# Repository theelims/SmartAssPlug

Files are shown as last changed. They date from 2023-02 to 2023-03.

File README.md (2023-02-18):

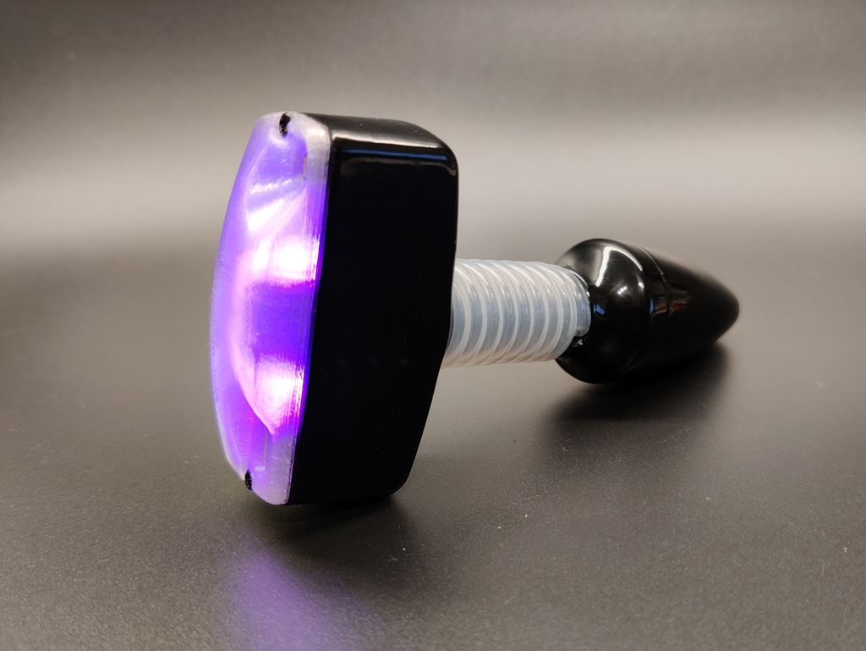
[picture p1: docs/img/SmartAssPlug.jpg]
SmartAss Plug


# SmartAss Plug - A Smart Butt Plug

Everything becomes "smart" these days. And there is no exception for butt plugs. While many butt plugs claim "smartness", just connecting it to the internet typically only means a remote control with more range. However **SmartAss Plug** has some more tricks up its sleeves. It's main purpose is not to vibrate a butt, but to sense and gauge sexual arousal. Having a reliable way to measure sexual arousal and orgasms opens up many possibility for the kinky minded person. Pneumatic anal probes have long time being the preferred choice in the clinical sector. However, in the kinky maker space the inflatable butt plug has gained more traction. Not least because of open source projects like the [nogasm](https://github.com/nogasm/nogasm) and the [protogasm](https://github.com/night-howler/protogasm). However, the inflatable butt plug suffers from a really bad signal to noise ratio. **SmartAss Plug** tries to build on these groundwork adding a more reliable sensor element, a more robust clench detection algorithm utilizing a kalman filter and calculus. All in a self-contained unit doing away any trip wires. In order to control a pleasure inducing device it connects to [XToys](https://xtoys.app/) or [buttplug.io](https://buttplug.io/) / [infitface](https://github.com/intiface/intiface-central).

Naturally it vibrates, too (kind of a the minimum requirement, obviously) and comes with more fun like a 9-DoF IMU and RGB Leds. Because, why not?

And last but not least, you are finally able to serve a website straight from your ass. How far has humanity come?

## Features

- Measures the involuntarily clenches of the pelvic floor to derive the arousal level of the wearer.
- Arousal classifier with the states "neutral", "aroused", "edging" or "orgasm".
- Vibration motor (plug sizes S & M only) for feedback, cheating in chess or stimulation.
- 9-DoF IMU to determine the absolute position of the plug for position training. (Not implemented, yet)
- Connects to your Wi-Fi or creates its own access point.
- Internal webserver to serve you the user interface straight from your butt.
- The inevitable RGB-led to make your butt shine colorful.
- Open WebSocket based API to integrate with your projects. (XToys and Buttplug.io support are pending)

## F.A.Q.

### What is the benefit of the coiled tube over an inflatable butt plug?

Using an inflatable butt plug is the traditional approach for edging and orgasm detection as introduced by the original nogasm. However, using this comes with some notable downsides. For some the size of these plugs can be daunting. Also the inflated portion - which is the actual sensor - sits behind the anal sphincter most of the time. As the signal we are looking for is the involuntarily clenching of the pelvic floor, the signal to noise ratio of an inflatable butt plug is not that great. It does pick up a lot of noise like breathing or even the heart beat. These signals can falsely trigger the algorithm leading to unsatisfying results. The coiled silicone tube sits exactly where the clenches happen resulting in a much cleaner signal to start with.

### Where can I buy this?

So far you can't buy it. You need to build it yourself sourcing all the required materials on your own. Consult the [sourcing guide](https://theelims.github.io/SmartAssPlug/sourcing/) for more information.

### Does it integrate with XToys or Buttplug.io?

SmartAss Plug offers a WebSocket API which makes it easy to integrate. XToys and Buttplug.io support is planned, but not implemented, yet.

### Is it available in different sizes?

Yes, the plug is available in 3 different sizes to accommodate a wide range of tastes.

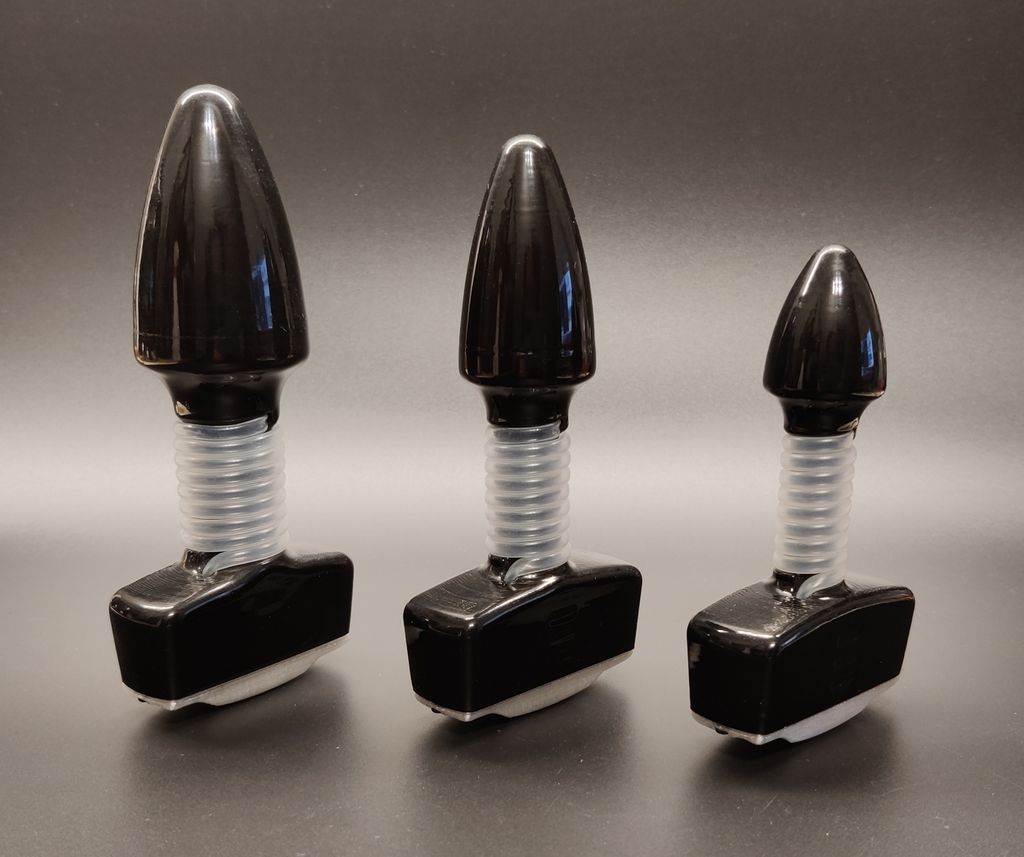
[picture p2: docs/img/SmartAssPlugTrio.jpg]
SmartAss Plug


|  Size  | Vibration | Diameter |
| :----: | :---: | :---: |
| **XS** | No |  25 mm |
| **S**  | Yes |  30 mm |
| **M**  | Yes |  38 mm |

## Contributors and Sources of Inspiration

- **Rudolf**, who came up with the [coiled silicone tube](https://www.thingiverse.com/thing:3543727) as sensor element and even has written a [scientific paper](https://www.degruyter.com/document/doi/10.1515/pjbr-2020-0014/pdf) on that topic.
- **Rhobot** with the original [nogasm project](https://github.com/nogasm/nogasm)
- **Onwrikbaar** with his bullfrog, who refined the simple [nogasm algorithm](https://github.com/Onwrikbaar/Bullfrog) with a peak summation and decay function.
- **night-howler** who contributed a breadboard friendly version of the nogasm called [protogasm](https://github.com/night-howler/protogasm).
- **Maus-Tec** who manufactures and sells the [Edge-O-Matic](https://github.com/MausTec/edge-o-matic-3000)
- **Skier23** who curates a [repository](https://github.com/Edging-Machines/Edging-Machines) and [discord](https://discord.gg/EvYbZBf) with all information regarding the topic.
- **Alex-R&D**

## License

Copyright &copy; 2023 by <a href="https://github.com/theelims"  target="_blank" rel="noopener">elims</a>

All work - software and hardware - is licensed under the

Creative Commons Attribution-ShareAlike 4.0 International Public License\*\*

For a full text of the license visit [CC-BY-SA 4.0](https://creativecommons.org/licenses/by-sa/4.0/).

# For further information visit the [project site](https://theelims.github.io/SmartAssPlug/).

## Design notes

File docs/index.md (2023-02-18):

---
hide:
  - navigation
  - toc
---

!!! warning "This project is in a very early stage"

    This project is in its infancy. The PCB may still contain undiscovered bugs. And a firmware is not yet available. Do not attempt to recreate this unless you really know what you are doing and want to contribute to this project.

<figure markdown>
  SmartAss Plug
</figure>

# SmartAss Plug - A Smart Butt Plug

Everything becomes "smart" these days. And there is no exception for butt plugs. While many butt plugs claim "smartness", just connecting it to the internet typically only means a remote control with more range. However **SmartAss Plug** has some more tricks up its sleeves. It's main purpose is not to vibrate a butt, but to sense and gauge sexual arousal. Having a reliable way to measure sexual arousal and orgasms opens up many possibility for the kinky minded person. Pneumatic anal probes have long time being the preferred choice in the clinical sector. However, in the kinky maker space the inflatable butt plug has gained more traction. Not least because of open source projects like the [nogasm](https://github.com/nogasm/nogasm) and the [protogasm](https://github.com/night-howler/protogasm). However, the inflatable butt plug suffers from a really bad signal to noise ratio. **SmartAss Plug** tries to build on these groundwork adding a more reliable sensor element, a more robust clench detection algorithm utilizing a kalman filter and calculus. All in a self-contained unit doing away with trip wires. In order to control a pleasure inducing device it connects to [XToys](https://xtoys.app/) or [buttplug.io](https://buttplug.io/) / [infitface](https://github.com/intiface/intiface-central).

Naturally it vibrates, too (kind of a minimum requirement, obviously) and comes with more fun like a 9-DoF IMU and RGB Leds. Because, why not?

And last but not least, you are finally able to serve a website straight from your ass. How far has humanity come?

## Features

- Measures the involuntarily clenches of the pelvic floor to derive the arousal level of the wearer.
- Arousal classifier with the states "neutral", "aroused", "edging" or "orgasm".
- Vibration motor (plug sizes S & M only) for feedback, cheating in chess or stimulation.
- 9-DoF IMU to determine the absolute position of the plug for position training. (Not implemented, yet)
- Connects to your Wi-Fi or creates its own access point.
- Internal webserver to serve you the user interface straight from your butt.
- The inevitable RGB-led to make your butt shine colorful.
- Open WebSocket based API to integrate with your projects. (XToys and Buttplug.io support are pending)

## F.A.Q.

### What is the benefit of the coiled tube over an inflatable butt plug?

Using an inflatable butt plug is the traditional approach for edging and orgasm detection as introduced by the original nogasm. However, using this comes with some notable downsides. For some the size of these plugs can be daunting. Also the inflated portion - which is the actual sensor - sits behind the anal sphincter most of the time. As the signal we are looking for is the involuntarily clenching of the pelvic floor, the signal to noise ratio of an inflatable butt plug is not that great. It does pick up a lot of noise like breathing or even the heart beat. These signals can falsely trigger the algorithm leading to unsatisfying results. The coiled silicone tube sits exactly where the clenches happen resulting in a much cleaner signal to start with.

### Where can I buy this?

So far you can't buy it. You need to build it yourself sourcing all the required materials on your own. Consult the [sourcing guide](sourcing.md) for more information.

### Does it integrate with XToys or Buttplug.io?

SmartAss Plug offers a WebSocket API which makes it easy to integrate. XToys and Buttplug.io support is planned, but not implemented, yet.

### Is it available in different sizes?

Yes, the plug is available in 3 different sizes to accommodate a wide range of tastes.

SmartAss Plug

|  Size  | Vibration | Diameter |
| :----: | :---: | :---: |
| **XS** | :material-close: |  25 mm |
| **S**  | :material-check: |  30 mm |
| **M**  | :material-check: |  38 mm |

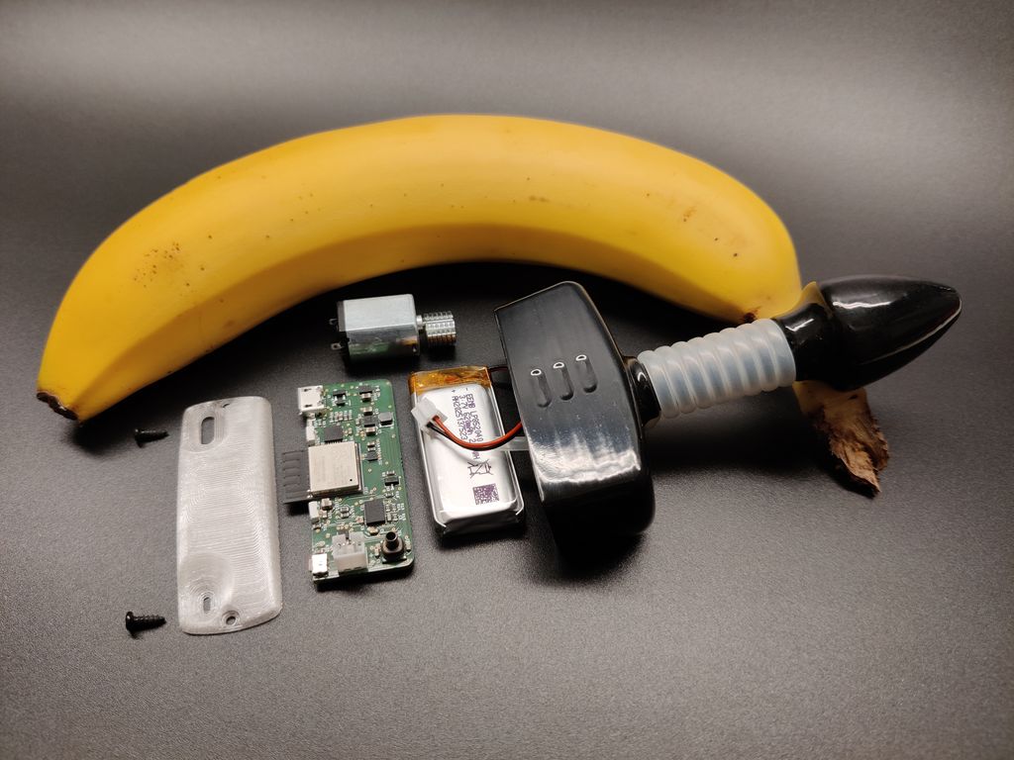
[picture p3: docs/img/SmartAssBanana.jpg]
SmartAss Plug


## Contributors and Sources of Inspiration

- **Rudolf**, who came up with the [coiled silicone tube](https://www.thingiverse.com/thing:3543727) as sensor element and even has written a [scientific paper](https://www.degruyter.com/document/doi/10.1515/pjbr-2020-0014/pdf) on that topic.
- **Rhobot** with the original [nogasm project](https://github.com/nogasm/nogasm)
- **Onwrikbaar** with his bullfrog, who refined the simple [nogasm algorithm](https://github.com/Onwrikbaar/Bullfrog) with a peak summation and decay function.
- **night-howler** who contributed a breadboard friendly version of the nogasm called [protogasm](https://github.com/night-howler/protogasm).
- **Maus-Tec** who manufactures and sells the [Edge-O-Matic](https://github.com/MausTec/edge-o-matic-3000)
- **Skier23** who curates a [repository](https://github.com/Edging-Machines/Edging-Machines) and [discord](https://discord.gg/EvYbZBf) with all information regarding the topic.
- **Alex-R&D**

## License

Copyright &copy; 2023 by <a href="https://github.com/theelims"  target="_blank" rel="noopener">elims</a>

All work - software and hardware - is licensed under the

**:fontawesome-brands-creative-commons: :fontawesome-brands-creative-commons-by: :fontawesome-brands-creative-commons-sa: Creative Commons Attribution-ShareAlike 4.0 International Public License**

For a full text of the license visit [CC-BY-SA 4.0](https://creativecommons.org/licenses/by-sa/4.0/).

!!! Question "Can I sell this on my webshop?"

    Yes, of course! You may start producing the PCB and the plug and sell it on your shop. The license was deliberately chosen to allow a commercial use by whoever is willing to go through the woes of starting their own business. However, the tech-kinky scene is rather limited in size and thus you must give back any improvements such that the kinky maker scene can take advantages of it. Please drop me a note if you sell it, so that I can include it into the sourcing guide.

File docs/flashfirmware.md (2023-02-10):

# Flash the Firmware

!!! info "Firmware not yet close to release"

    The firmware is still under heavy development. So far all parts of the PCB have confirmed to work as expected.

Join the [Kinky Makers Discord](https://discord.gg/hephqY2m8A) and follow the _#elims-smartass-plug-edging-device_ channel to receive regular updates on the development.

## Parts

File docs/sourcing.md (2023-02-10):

# Source all Parts

As you can't buy the plug off the shelf making it is up to you. This might be daunting at first, but if you already own a 3D printer you figured out the hard part already. But even if you don't own a printer yourself there are numerous service providers out happily accepting your money. Same goes for the electronics. You can practice SMD assembly and order the board from your preferred PCB house. Or you can throw money at the problem and get ready made and assembled boards from several sources in China.

## Tools needed

- 3D printer
- Soldering Iron + Solder (SmartAss Plug S & M only)
- Sandpaper, various grids starting from 120 and finer
- Scotch-Brite red and black
- Scissors
- Screwdriver Philipps #1
- Cleaned pickles jar, big enough for the intended plug size
- Acetone
- Paper Towel
- Acetone-proof brush
- IPA and lint-free cloth
- fine tipped tweezers

## Bill of Material Plug

| Component | Size | Qty | Source | Notes |
| :--- | :--- | :-- | :--- | :--- |
| Vibration Motor FF-030 | FF-030 | 1 | [AliExpress](https://www.aliexpress.com/item/1005003722404804.html) | Only for Plug Size S |
| Vibration Motor Mini 130 | 130 | 1 | [AliExpress](https://www.aliexpress.com/item/1005002947312785.html) | Only for Plug Size M |
| LiPo Battery 620mAh | LP852040 | 1 | [Amazon](https://www.amazon.de/gp/product/B095VVWTSH/) | LiPo 20mm x 40mm, thickness up to 10mm |
| Silicone Tube | ID 2mm OD 3mm | 1m  | [Amazon](https://www.amazon.de/gp/product/B075ZPR794/) | Must be thin walled silicone tube |
| Inner Spring | 0.2mm x 45mm x 2mm | 1 | [AliExpress](https://www.aliexpress.com/item/1005001304880787.html) |
| Outer Spring | 0.4mm x 10mm x 4mm | 1 | [AliExpress](https://www.aliexpress.com/item/1005001304880787.html) |
| Philipps Pan Head Screws | 2mm x 6mm | 2 | [Amazon](https://www.amazon.de/gp/product/B00GMQDSRI) |
| Silicone Wire | 28AWG or 26AWG | 1m  | [Amazon](https://www.amazon.com/DAOKI-Silicone-Stranded-Electrical-Assortment/dp/B08PBLTYD8/) | Only for Plugs with vibration motor |

## Electronics

!!! info "Buying ready-made boards"

    As of now, you need to source the PCB yourself and take care of the assembly. But I hope that someone will make this board available to buy in the near future (already in negotiation).

The [hardware folder](https://github.com/theelims/SmartAssPlug/tree/main/hardware/PCB) contains the PCB design files exported from Fusion360 as Eagle 9.X compatible format. It opens in eagle, however it throws some error messages because font's are not supported. With the files you should be able to create the required Gerbers for your board house of choice. Double check the silk screen layers, as the font might be off.

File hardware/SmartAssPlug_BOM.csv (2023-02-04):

Component | Size | Qty | Source | Notes
Vibration Motor FF-030 | FF-030 | 1 | https://www.aliexpress.com/item/1005003722404804.html | Only for Plug Size S
Vibration Motor Mini 130 | 130 | 1 | https://www.aliexpress.com/item/1005002947312785.html | Only for Plug Size M
LiPo Battery 620mAh | LP852040 | 1 | https://www.amazon.de/gp/product/B095VVWTSH/ | LiPo 20mm x 40mm thickness up to 10mm
Silicone Tube | ID 2mm OD 3mm | 1m | https://www.amazon.de/gp/product/B075ZPR794/ | Must be thin walled silicone tube
Inner Spring | 0.2mm x 45mm x 2mm | 1 | https://www.aliexpress.com/item/1005001304880787.html
Outer Spring | 0.4mm x 10mm x 4mm | 1 | https://www.aliexpress.com/item/1005001304880787.html
Philipps Pan Head Screws | 2mm x 6mm | 2 | https://www.amazon.de/gp/product/B00GMQDSRI

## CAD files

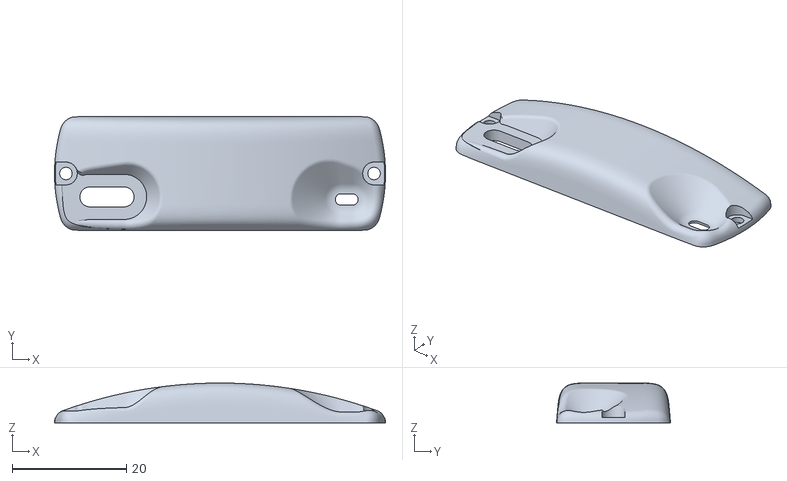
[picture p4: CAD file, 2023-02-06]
hardware/STL/[T]_SmartAssPlug_Cap.stl
58.0 x 20.0 x 7.00

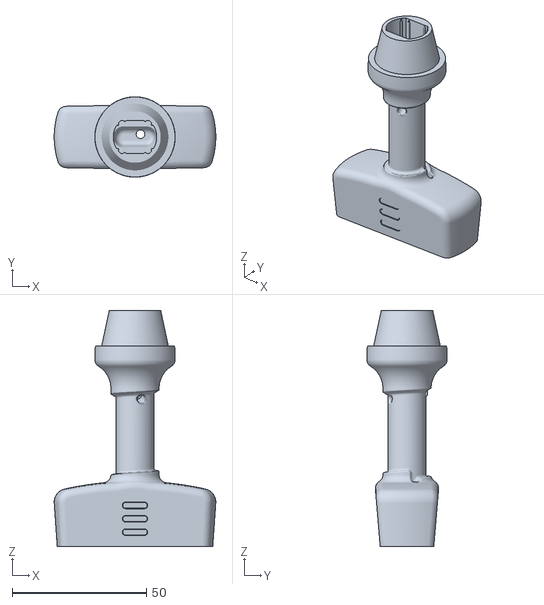
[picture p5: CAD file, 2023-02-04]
hardware/STL/SmartAssPlug_S_Plug.stl
60.3 x 30.0 x 88.0

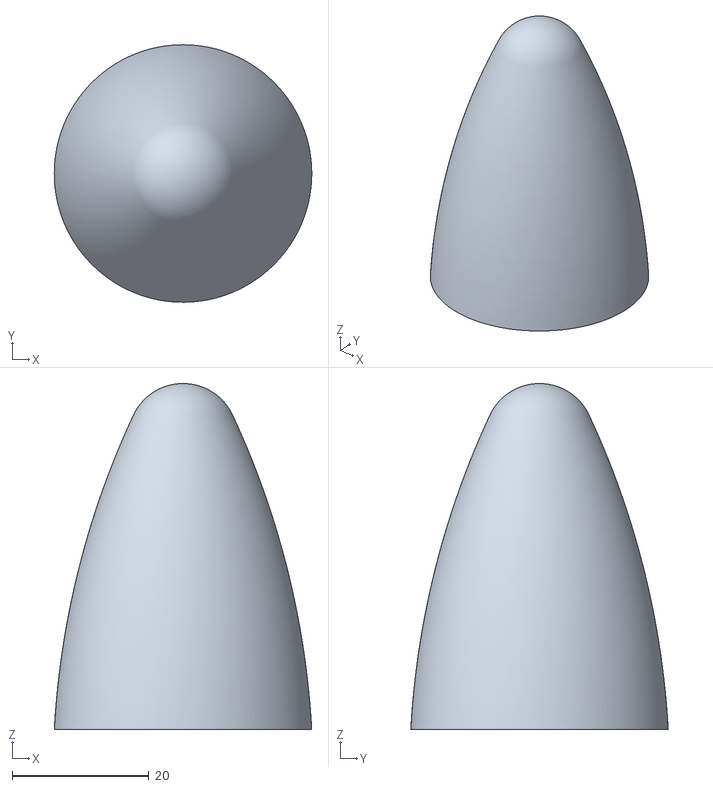
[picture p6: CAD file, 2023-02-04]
hardware/STL/SmartAssPlug_M_Tip.stl
37.6 x 37.6 x 50.5

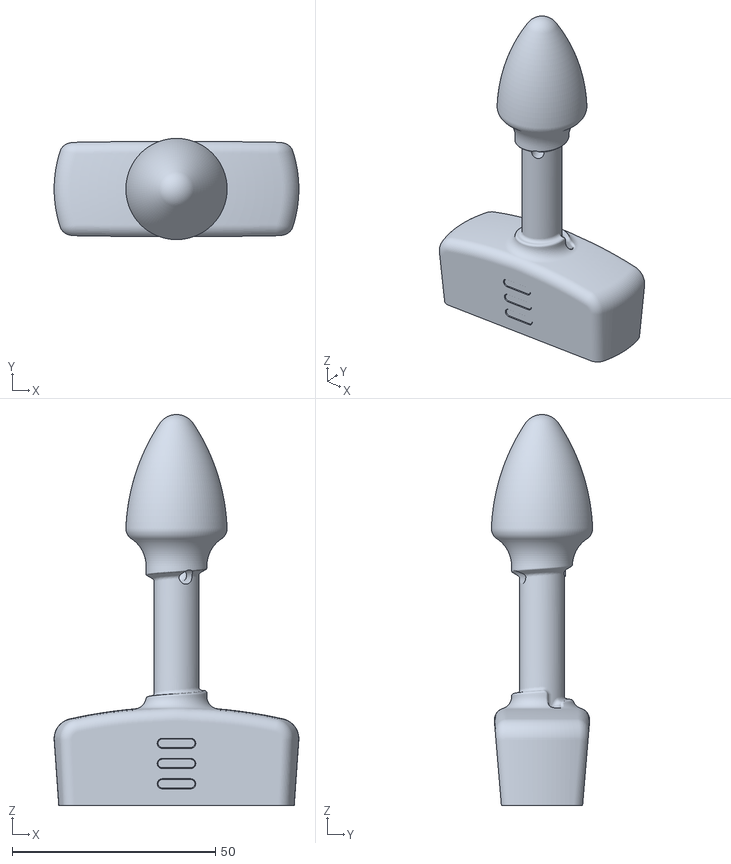
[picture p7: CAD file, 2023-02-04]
hardware/STL/SmartAssPlug_XS.stl
60.3 x 24.9 x 96.3

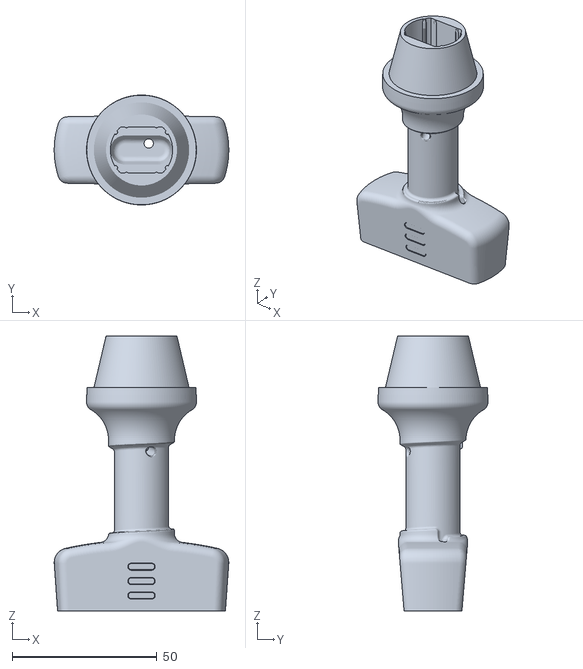
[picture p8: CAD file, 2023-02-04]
hardware/STL/SmartAssPlug_M_Plug.stl
60.3 x 38.0 x 95.0

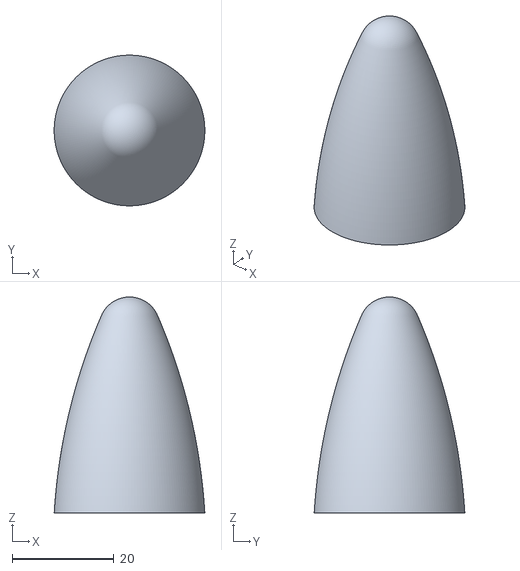
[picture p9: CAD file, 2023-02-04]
hardware/STL/SmartAssPlug_S_Tip.stl
29.6 x 29.6 x 42.4

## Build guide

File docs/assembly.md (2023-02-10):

# Assemble the Plug

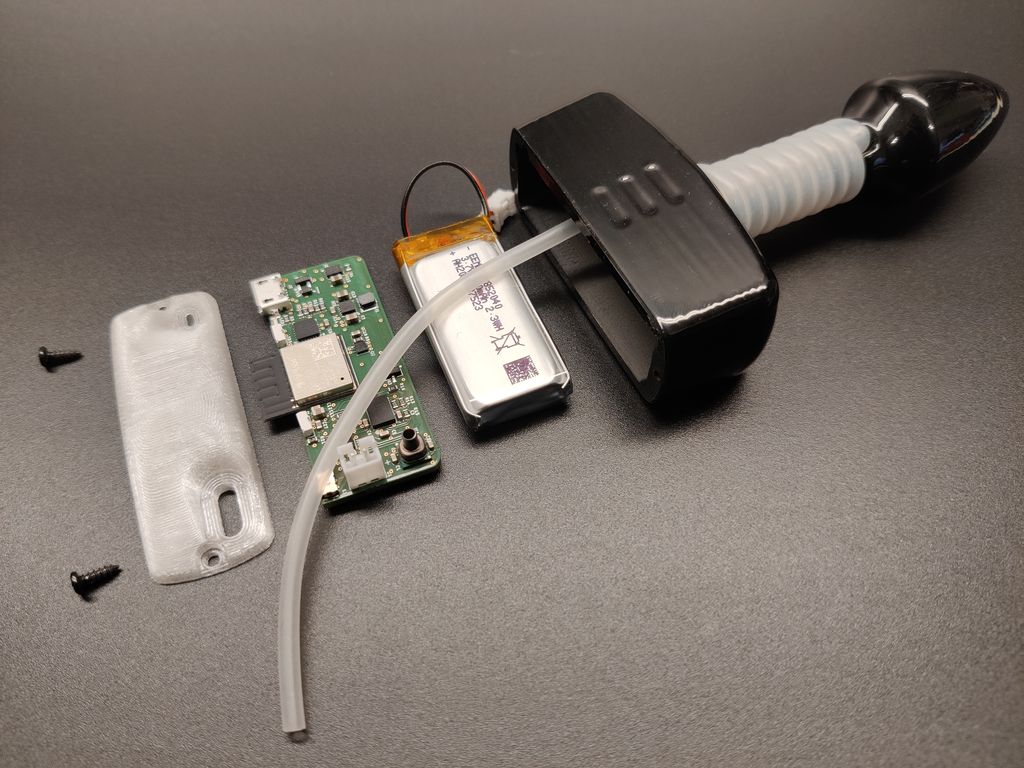
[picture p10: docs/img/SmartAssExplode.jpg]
SmartAss Plug Assembly


Assembly of a SmartAss Plug is not difficult. But take your time and do the steps with care to achieve the optimal result.

## Installing the Vibration Motor

!!! info "This chapter does not apply for the SmartAss Plug XS"

    The SmartAss Plug XS does not feature a vibration motor. You can omit this step and continue with vapour smoothing.

As a very first step check wether the tip fits nicely on the plug. By slightly screwing the tip on it should stick without leaving a visible gap. If your seems are noticeable, sand them on the inside and the outside of the conus.

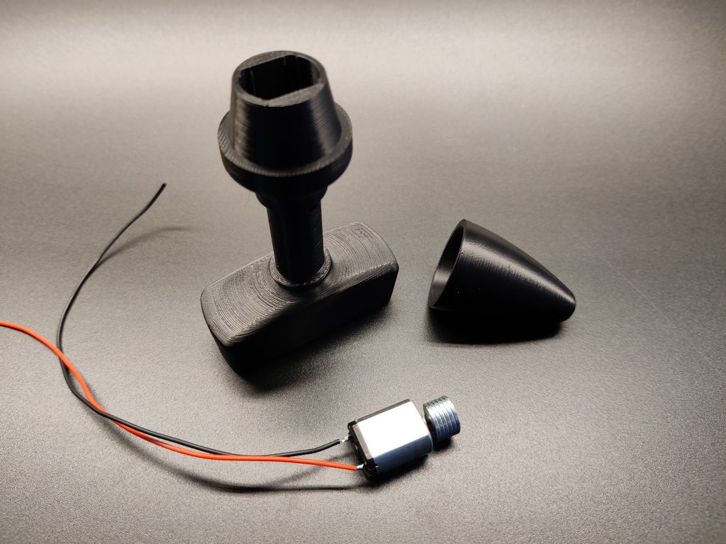
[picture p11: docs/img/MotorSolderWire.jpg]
SmartAss Plug Wires


Soldering around 20-30 cm of silicone wire onto the motor terminals of the vibration motor. The polarity or the color of the wires doesn't matter. Carefully thread the wires one-by-one through the center hole into the main body.

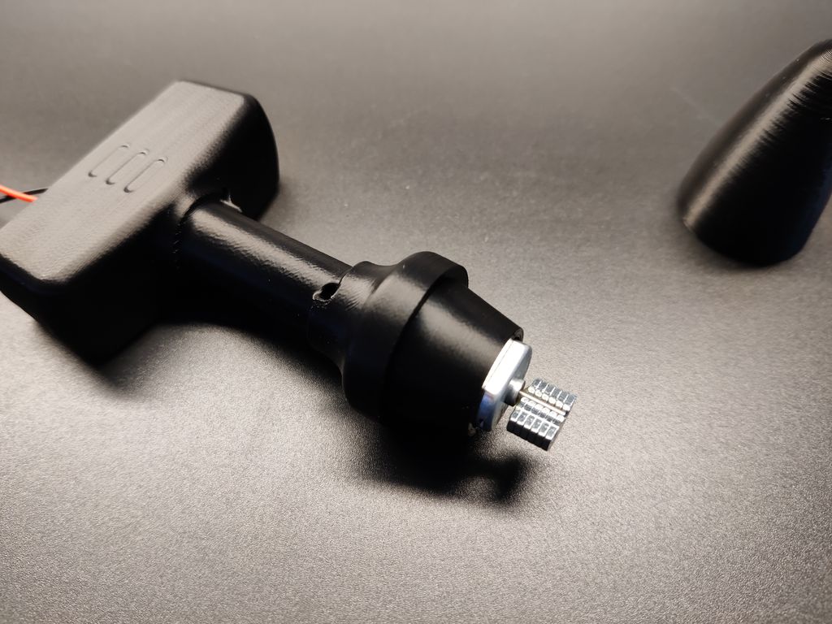
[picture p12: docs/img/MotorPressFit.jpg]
SmartAss Plug Press Fit


Press the motor into the press-fit of the plug. This requires some force. If not, then you should consider working on your printers dimensional accuracy and reprint the part. The housing of the motor should only sick around 1-2 mm out of the plug's body.

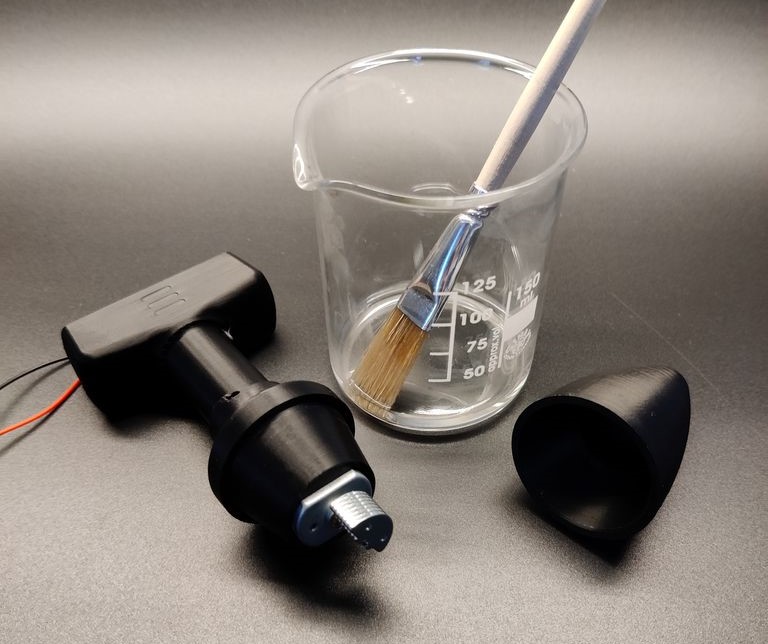
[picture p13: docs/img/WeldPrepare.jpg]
SmartAss Plug Prepare Weld


Prepare the weld by preparing some acetone and a acetone-proof brush. ASA and ABS can be welded by dissolving the surface with acetone. This weld is extremely strong and destructive testing showed, that it is impossible to destroy.

!!! warning "This will only work if you have printed the parts in ASA or ABS"

    If you've printed your plug in an other material check what kind of solvent you need to do the weld. Glueing should be possible as well, but won't lead to nice results.

!!! danger "Welding is a critical step!"

    The acetone evaporates rather quick. The parts must be pressed on wet on both sides of the cone. Work quickly and accurate. Rework is not possible once it is welded.

<div style=flex>
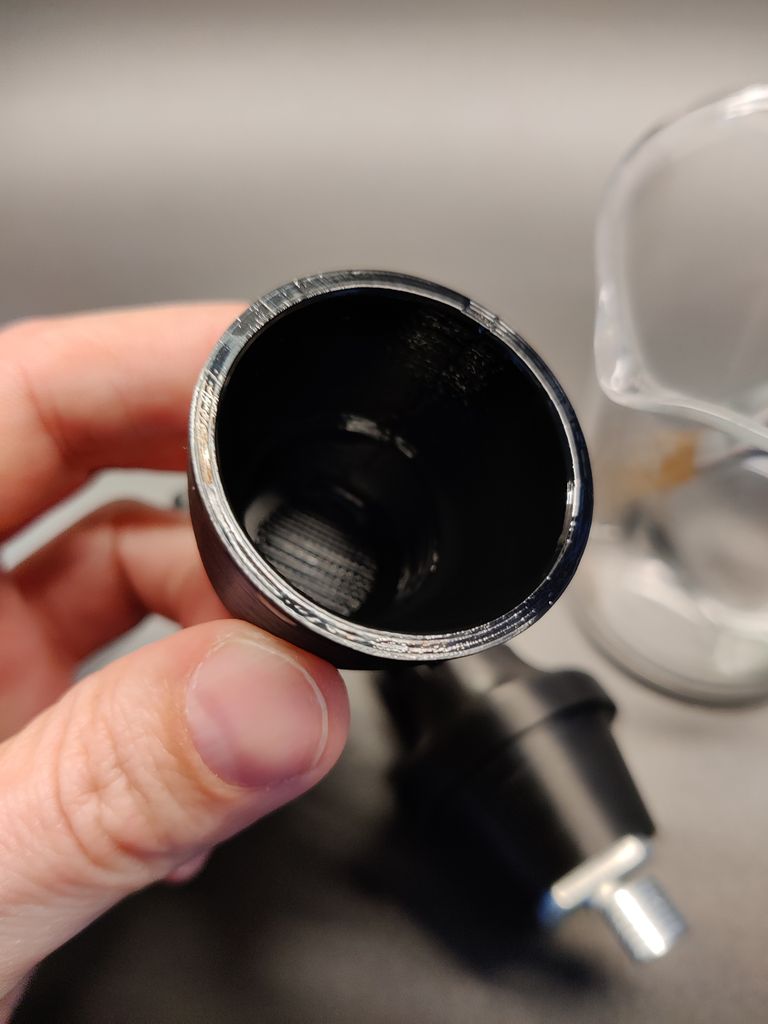
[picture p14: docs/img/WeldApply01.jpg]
 
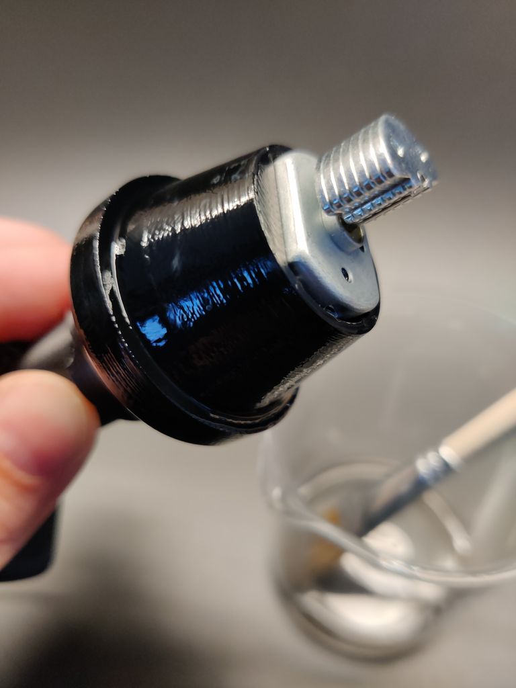
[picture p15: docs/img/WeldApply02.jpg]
 
</div>
Apply the acetone on both, inside and outside of the cones. Work quickly, as the acetone evaporates fast. Add a second or third round of acetone if needed. The parts must be pressed together wet in wet. Don't mind if the acetone will run onto other parts of your print. This will be taken care of during post processing.

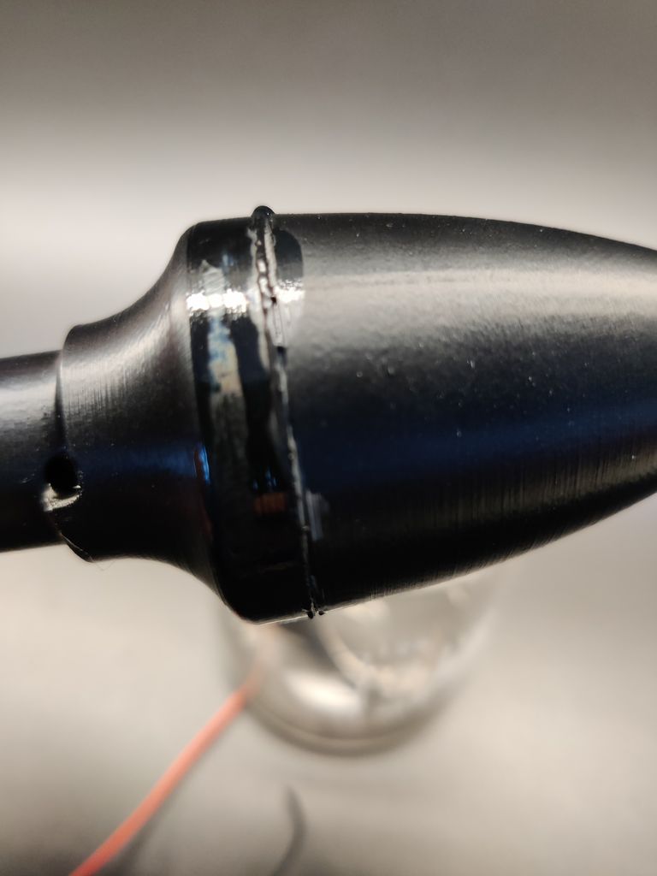
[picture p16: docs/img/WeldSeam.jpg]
SmartAss Plug Weld Seam


Press the tip on the plug with as much force as possible. A twisting motion will distribute molten plastic inside the seam and fill the gaps. The ideal seam will noticeably bulge.

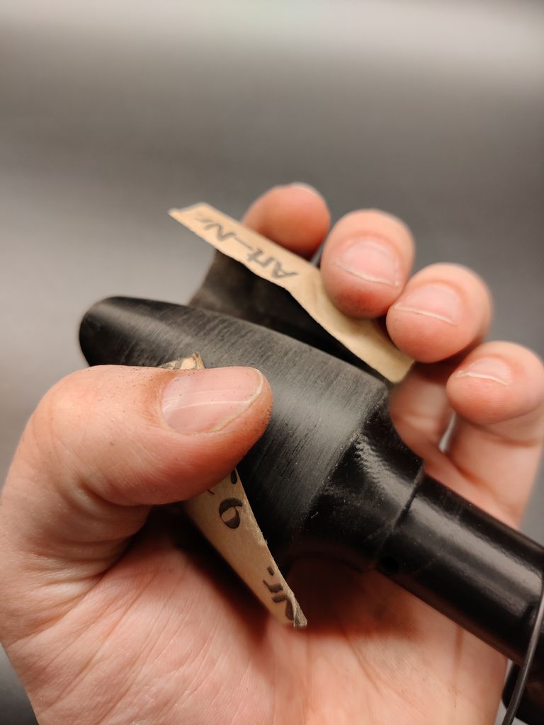
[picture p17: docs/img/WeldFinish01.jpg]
SmartAss Plug Sanding Seam


Once the weld has solidified you can start sanding away the seam with sandpaper. Start with 120 grid and work towards finer grids.

## Vapour Smooth the Plug

!!! warning "This will only work if you have printed the parts in ASA or ABS"

    If you've printed your plug in an other material check what kind of solvent you need to do the polishing. Or you need to do the post processing completely manual.

!!! danger "Acetone is Dangerous!"

    Acetone is a dangerous chemical. It is highly inflammable and can lead to explosives atmospheres. Read the MSDS that comes with your bottle of acetone. Do the vapour smoothing only in a well ventilated area, preferably outside. Take precautions and keep away any ignition source (electronics, fire, heater, ...)

For an optimal, high-gloss, germ friendly and watertight finish the plug must be polished with acetone fumes. For optimal results you should sand away the layer lines.

<div style=flex>
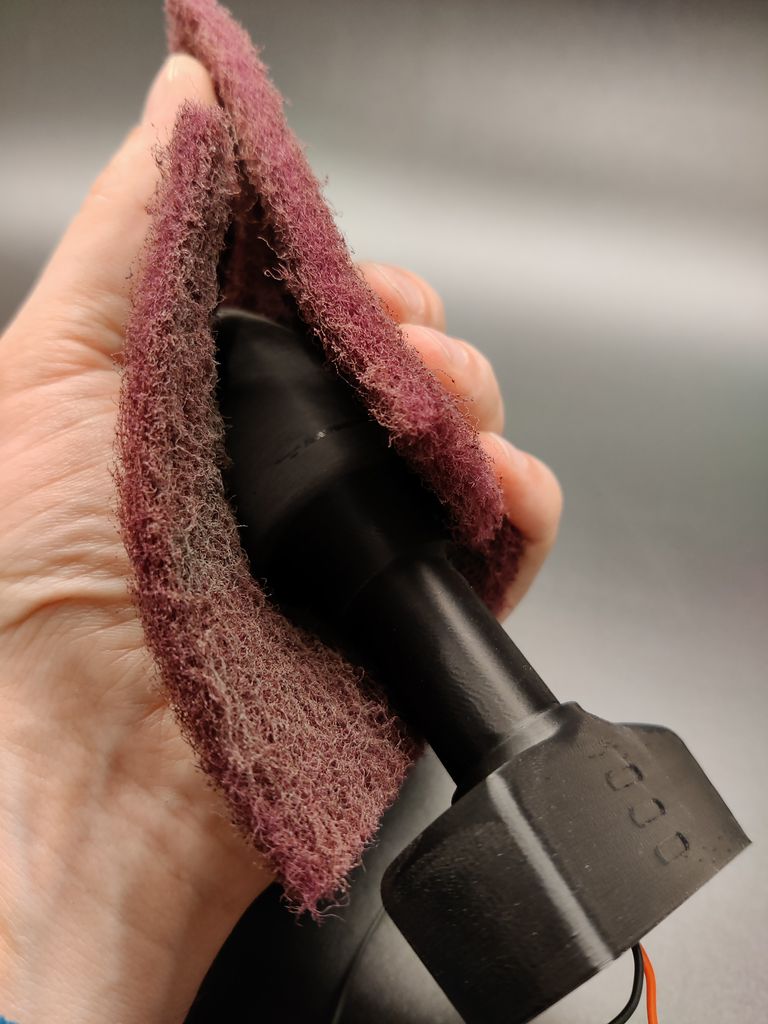
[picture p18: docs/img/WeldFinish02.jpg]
 
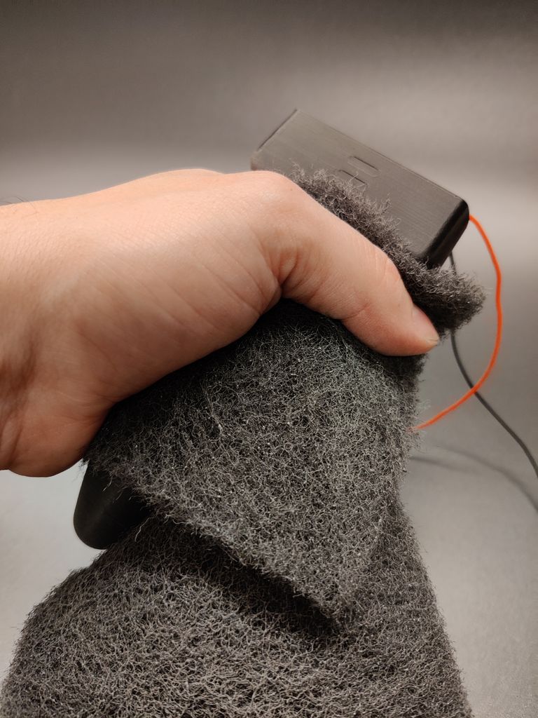
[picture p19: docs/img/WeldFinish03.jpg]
 
</div>

Start with fine sandpaper and continue with the scotch-brite. First the red, medium coarse. And finally the black fine non-woven. Take your time for this step. The better the layer lines disappear, the better will be the polished results.

Remove any dust and finger prints from sanding with IPA and a lint-free cloth. If you have a plug with vibration motor stow away te excess cables inside the electronics compartment.

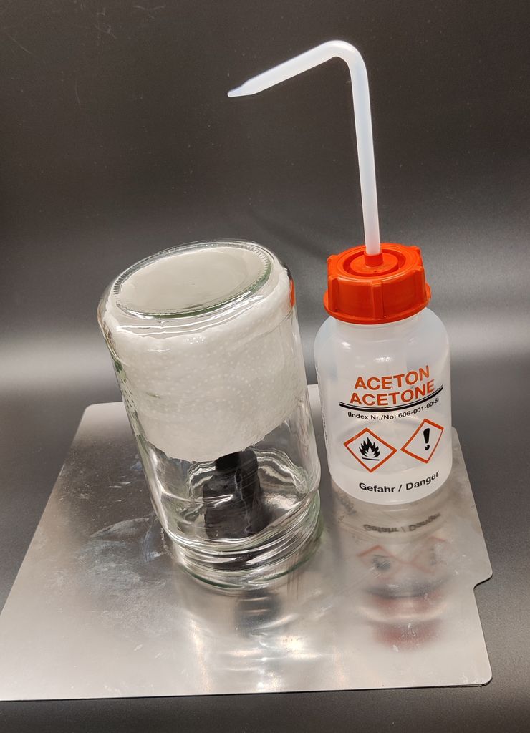
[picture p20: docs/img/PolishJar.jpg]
SmartAss Plug Acetone Polish


Use a pickles jar big enough to contain the whole plug. Inside the jar place some paper towels to hold the acetone. This should be at the very top of the jar, so that the acetone vapour concentration is also up there. Wet the paper towels with acetone. Make sure that you do not over-saturate them. There should be no acetone running down the sides.

Place the plug on a acetone proof surface like a metal build plate and let the vapour do its magic. Depending on the temperature and the filament brand this can take up to 30-60 minutes.

!!! tip "Test the process with a benchy"

    Test how your particular filament brand smooth with some excess benchies.

Once the time is up remove the jar and let the plug dry. Do not touch the plug until it's fully solidified again. Properly discard the acetone and let it evaporate outside.

## Install the Silicone Tubing

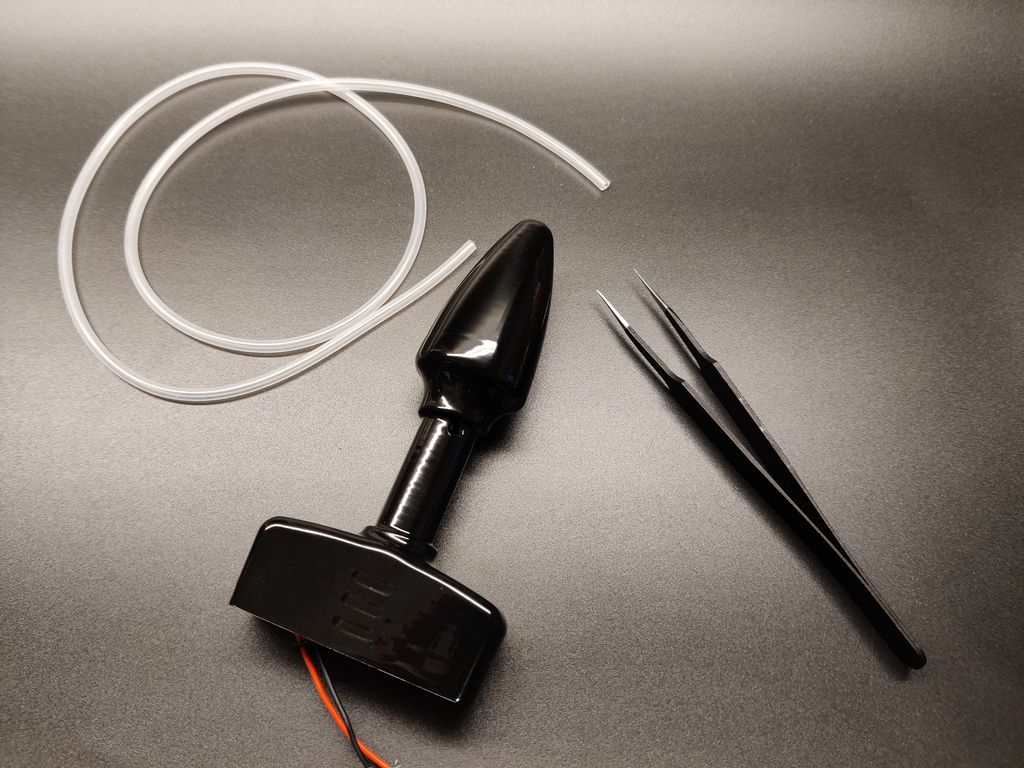
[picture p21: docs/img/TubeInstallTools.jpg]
SmartAss Plug Tube Installation


To install the silicone tube which serves as the pressure sensor you'll need a fine tipped tweezer. The installation is a little bit fiddly, but with the right tricks not that hard.

<div style=flex>
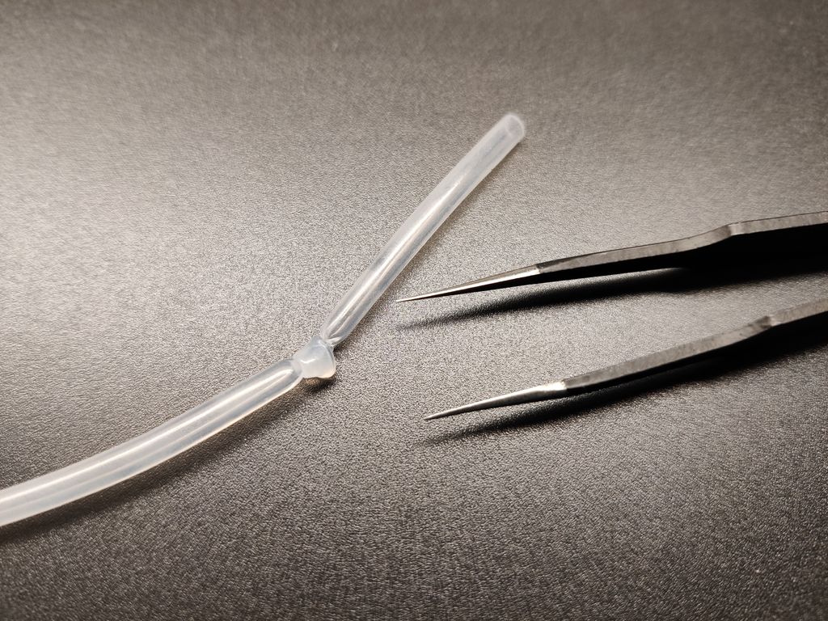
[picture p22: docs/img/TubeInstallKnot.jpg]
 
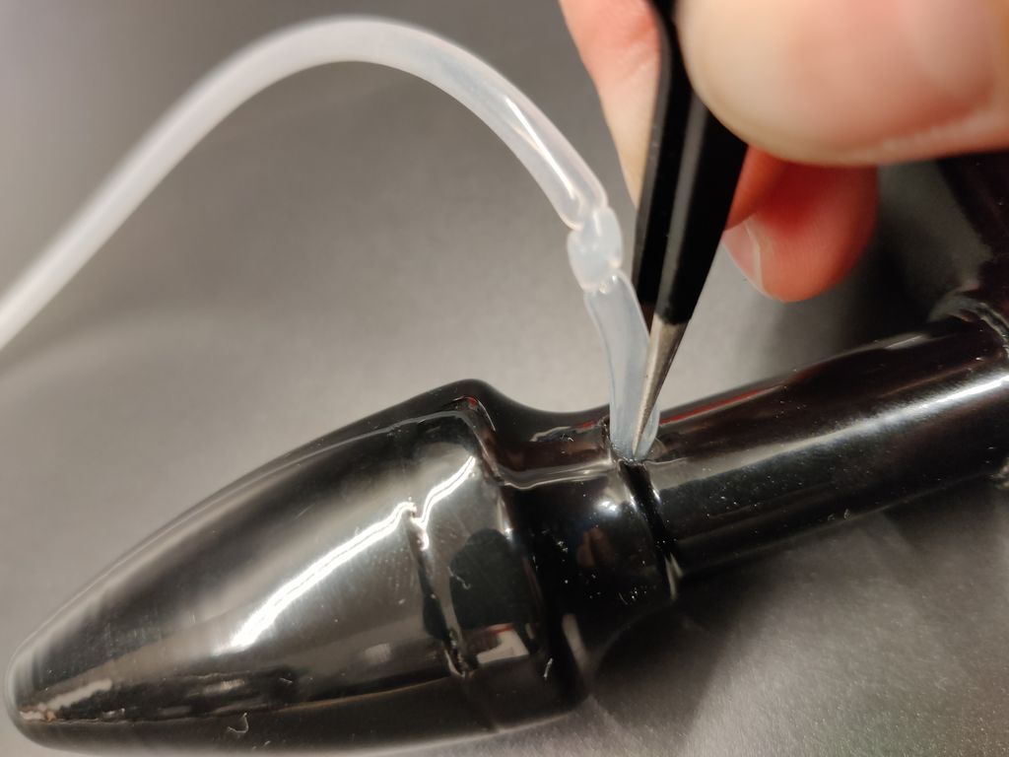
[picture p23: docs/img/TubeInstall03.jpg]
 
</div>

Start by making a single knot 5-6 cm away from the tube end. Pull the knot really tight. It will seal the one end of the tube. Use the tweezers to push the short end into the hole where the tube will later exit to form the coil. Inside that hole there is a special cavity for the knot. Try to push the tube as deep inside the cavity as possible.

!!! warning "Don't Damage the Tube"

    These tweezers are quite sharp and easily puncture the tube. Be especially cautious.

<div style=flex>
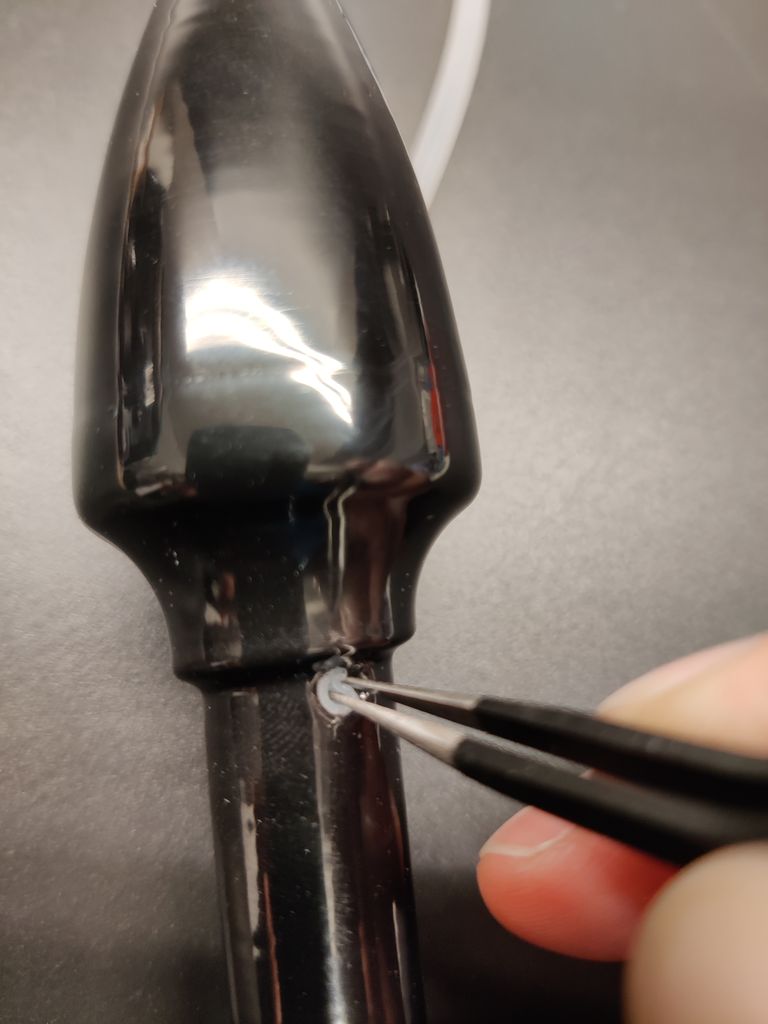
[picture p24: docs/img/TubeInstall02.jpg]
 
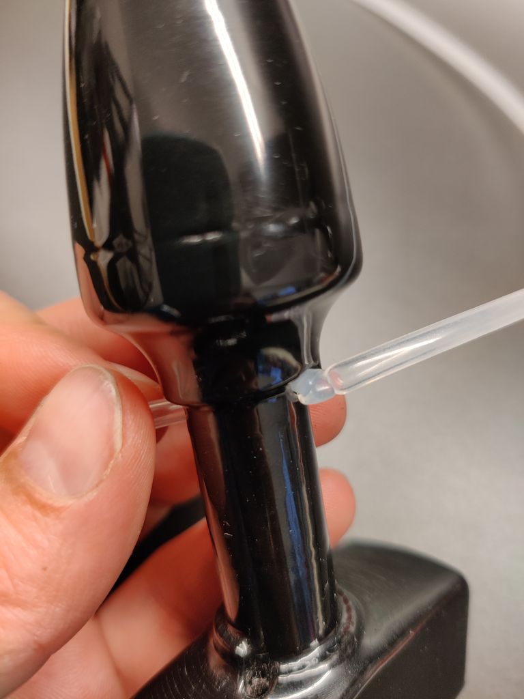
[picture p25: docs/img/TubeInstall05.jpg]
 
</div>

Then try to grab the end of the tube from the other side (this hole will be hidden later) and pull it through. Gently pull it until the knot is at the hole. Then try to pull the knot inside the cavity. This requires some force and most likely it will snap right through and exit on the other side. Don't panic. Pull it gently back into the cavity, while holding the short end under tension. With this trick the knot will stay safely inside the plug.

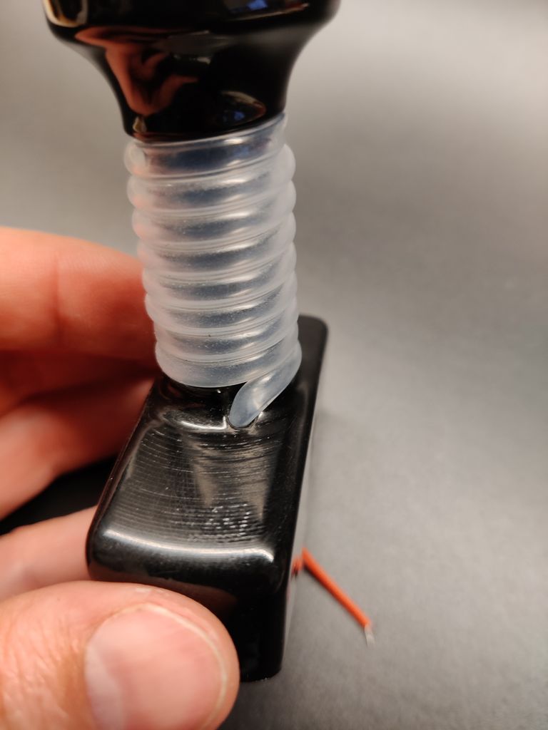
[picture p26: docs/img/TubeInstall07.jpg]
SmartAss Plug Tube Installation


Finally wrap the tube around the shaft of the plug. Apply a slight tension so that the winding is tight and compact. Finally thread the remaining tube through the bottom hole. Use the tweezers to assist in the task.

## Mount the PCB

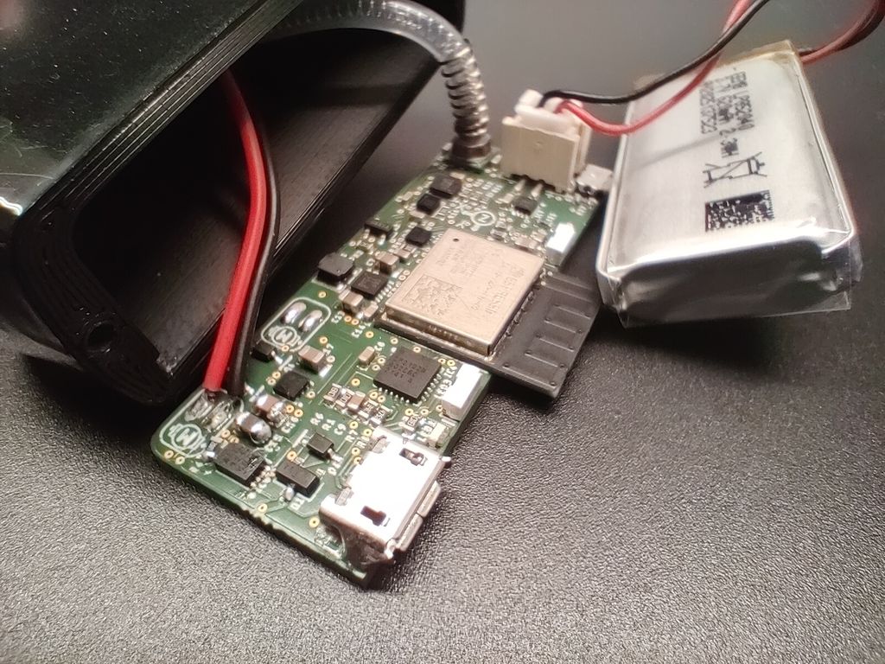
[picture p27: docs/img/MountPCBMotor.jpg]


Cut the vibration motor wires to around 30-40 mm measured from where the leave the shaft. Solder them to one set of motor pads. You can use either of the motor solder pads.

<div style=flex>
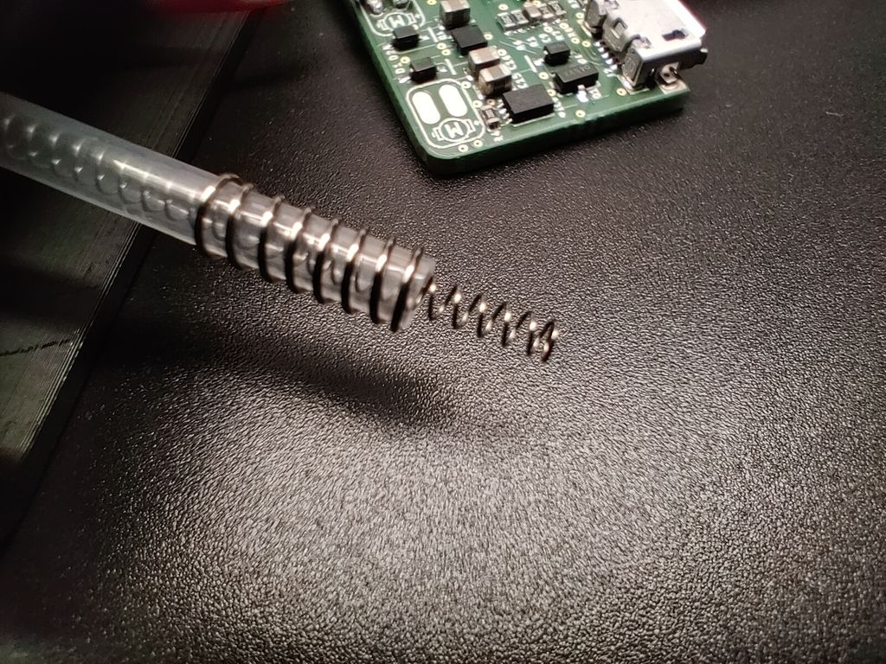
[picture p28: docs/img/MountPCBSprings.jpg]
 
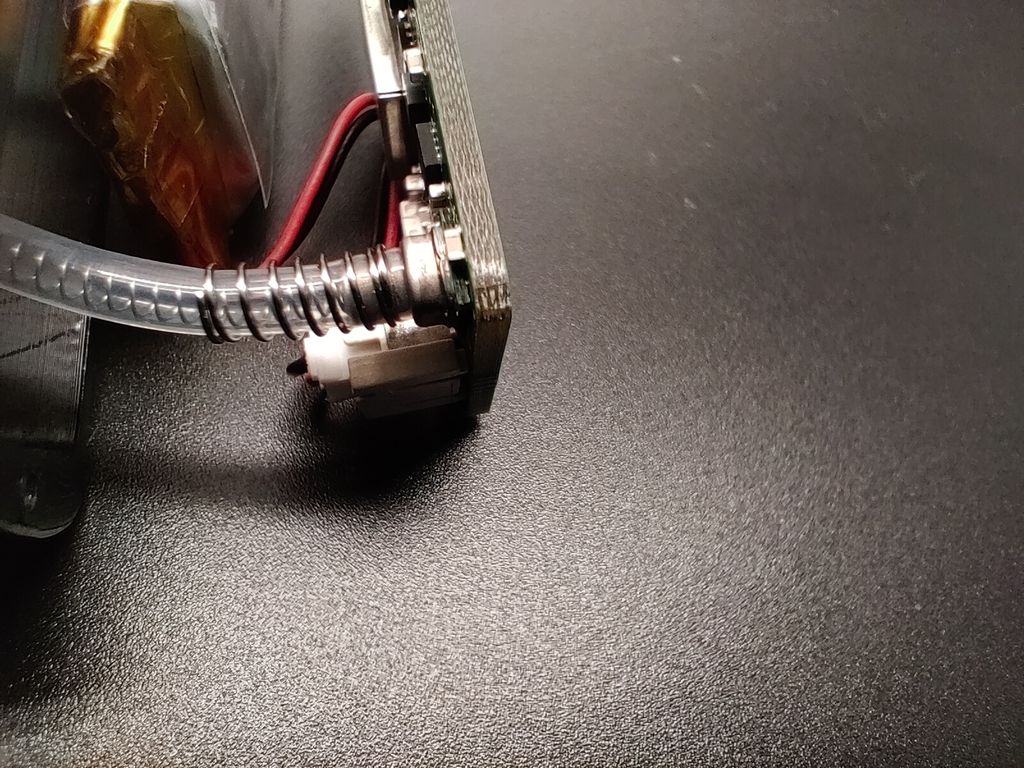
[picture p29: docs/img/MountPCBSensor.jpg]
 
</div>

!!! warning "The Springs are Mandatory"

    These springs are extremely important for the plug to work properly. The silicone tube is very thin walled and kinks easy in bends. Inside the electronics compartment it is very tight and the tube needs well defined bends. The springs will prevent the walls of the tube from collapsing. If you leave the springs out the probability is very high, that your plug won't work.

Cut the silicone tube to 40 mm measured from where it enters the electronics compartment. Push the 2 mm x 45 mm spring into the tube. It should stick out 3-5 mm when completely pushed in. If you've cut the tube too short, you can massage a few millimeters out of the coil. It is important, that the inner spring has some compression. Push the 4 mm x 10 mm outer spring over the tube, so that it sits flush with the bottom.

Then press the tube and springs over the port of the pressure sensor. The outer spring serves both as a retainer clip, as well as a kink protection for the very tight bend right after the sensor.

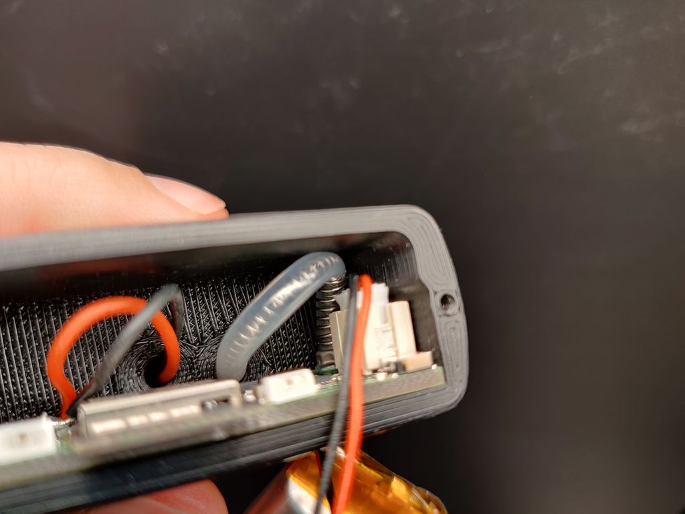
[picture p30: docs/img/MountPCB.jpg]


Install the battery in the connector. Check the polarity of your battery with the **+** and **-** symbols on the PCB's silkscreen. If your battery has a reversed polarity use a thin needle to remove the crimp connectors out of the plug and push them in in the right order. Don't short the battery in the process.

!!! danger "Double Check the Polarity of the Battery"

    **Failing to do so will inevitably damage your PCB!** There is no reverse polarity protection for the battery.

Gently slide the PCB into the recess of the plug's body. The silicone tube will twist itself in in the exact right way.

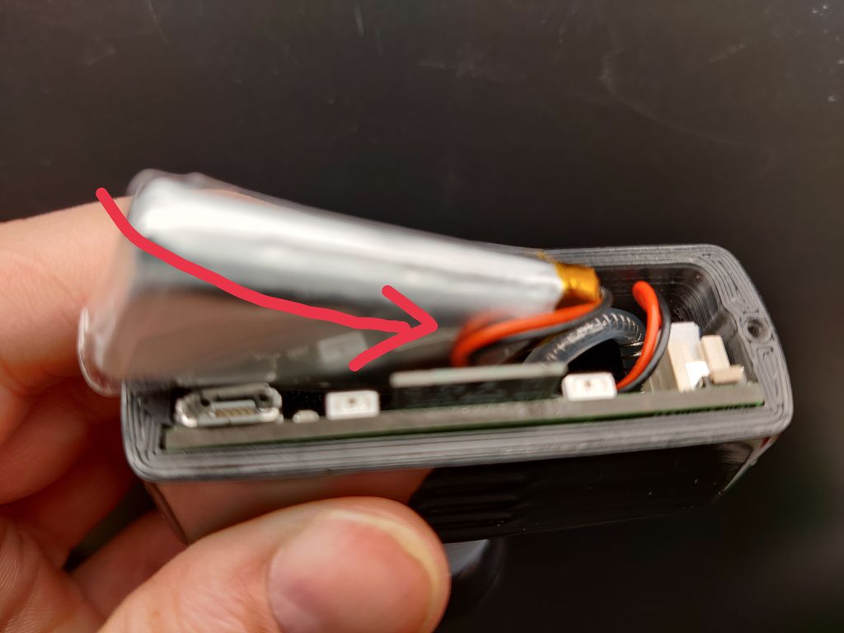
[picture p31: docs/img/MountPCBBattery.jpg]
SmartAss Plug Battery Installation


Install the battery as shown in the picture. The part with the protection PCB must go to the battery connector side giving room for the silicone tube. If the wires of the motor get in your way, or get stuck under the battery use tweezers or a screwdriver to position them between the ESP's shield and the battery. Same goes for the wires of the battery itself.

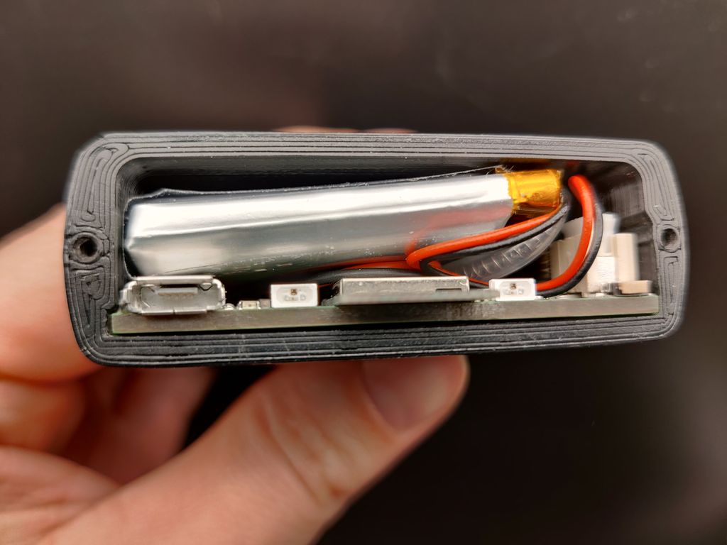
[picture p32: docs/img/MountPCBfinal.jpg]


The final result should look like this. The wires for the motor and the battery should fit between battery and the PCB. Last but not least mount the transparent cap with the two screws and start charging the battery.

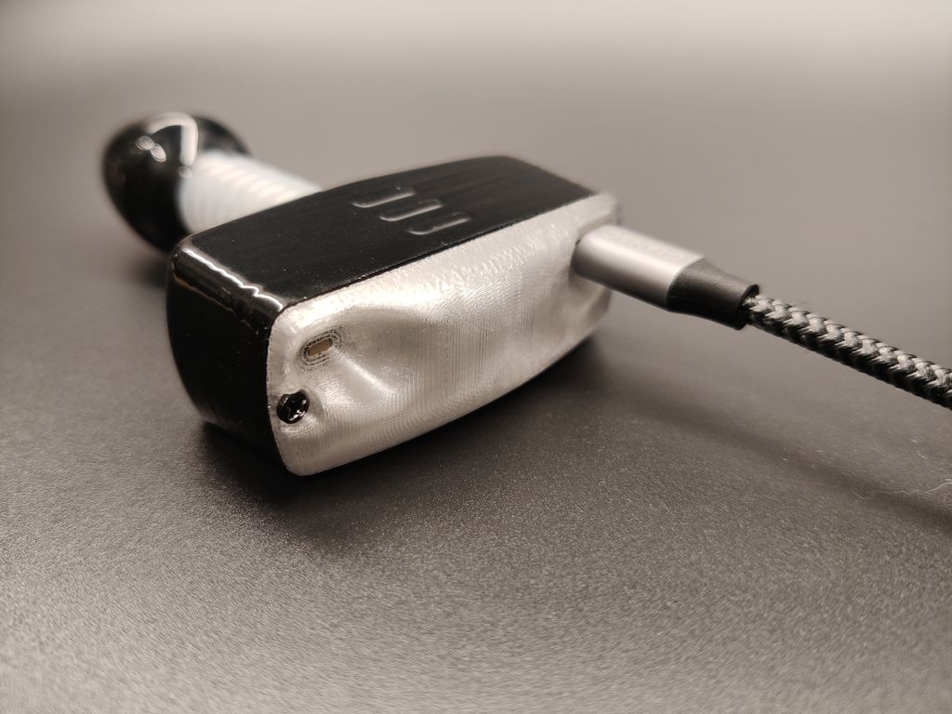
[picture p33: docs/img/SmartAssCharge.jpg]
SmartAss Plug Battery Completed


Take a moment and enjoy the results of your hard work. Your plug is ready to receive the firmware now.

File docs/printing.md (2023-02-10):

# 3D Printing

## Recommended Filaments

For the body of the SmartAss Plug ASA and ABS are recommended as filament. Purchase a quality brand as the print quality can vary greatly between brands. If possible buy a blend where the raw materials that go into the filament are FDA approved for food contact. If you have never printed either ASA or ABS go with ASA. Not only does it emit considerable less nasty fumes, but also does it generally posses more favorable print properties. As the parts are rather small ASA can be printed on open frame printers like an Ender or Prusa without too much worries.

Be sure to test the vapour smoothing properties of your specific ABS / ASA blend. Some blends polish barely due to additives.

!!! warning "It is strongly recommended to use ASA or ABS"

    Inserting 3D printed parts into the body is not without dangers. The mechanical properties and the force to break the plugs neck haven been optimized with ASA. It takes considerable force - unlikely to encounter in a real world application - to break the plug in half. Also the fact that 3D printed parts are typically not water tight and have a rough surface makes them less then ideal for inserting them into the body. Both issues can be somewhat mitigated by the ability to vapour smooth ASA and ABS prints. Also both materials can be purchased in FDA approved food safe qualities.

For the cap a transparent filament is needed. Generally speaking this boils down to PET, PETG or PCTG as the filament choice. The cap is used to diffuse two RGB leds.

## Print Settings

### Plug Body

These print settings are recommended for optimal results:

- Nozzle: 0.4 mm
- Perimeters: 4
- Layer height: 0.1 mm
- Top / Bottom Solid Layers: 10
- Infill: 40% Rectilinear
- Smooth build surface

All parts print without supports enabled. Except for _SmartAssPlug_S_Plug.stl_ and _SmartAssPlug_M_Plug.stl_ which need support inside the electronics compartment. For these enable supports from the build plate only.

!!! tip "Suffers from poor surface finish where the main body slopes towards the neck?"

    Due to the thin layer height of the top solid layers they can sink in on the shallow sloped top surface. If you run into this issue, then use a height modifier in the slicer for these few millimeters and modify the infill to 100%.

### Transparent Cap

Since this part must diffuse the RGB leds it must be printed with optical properties in mind. Best results I got with these settings:

- Nozzle: 0.4 mm
- Perimeters: 30
- Layer height: 0.1 mm
- Top / Bottom Solid Layers: 1
- Infill: 100% Rectilinear

The heigh count of perimeters lines makes the slicer print the part in concentric lines and had prettier results then concentric infill. Basically we want a solid part.

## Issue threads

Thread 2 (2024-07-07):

Gerber files?

whinee, 2024-07-07:
Can you release gerber files for the PCB? thanks!

theelims, 2024-07-07:
Hi, you can import the *.brd and *.sch files into Fusion and generate Gerbers. I do not see the point of releasing the gerbes. Please use the files from the dev branch which fixes a critical error on the first PCB.

Closed 2024-07-07.

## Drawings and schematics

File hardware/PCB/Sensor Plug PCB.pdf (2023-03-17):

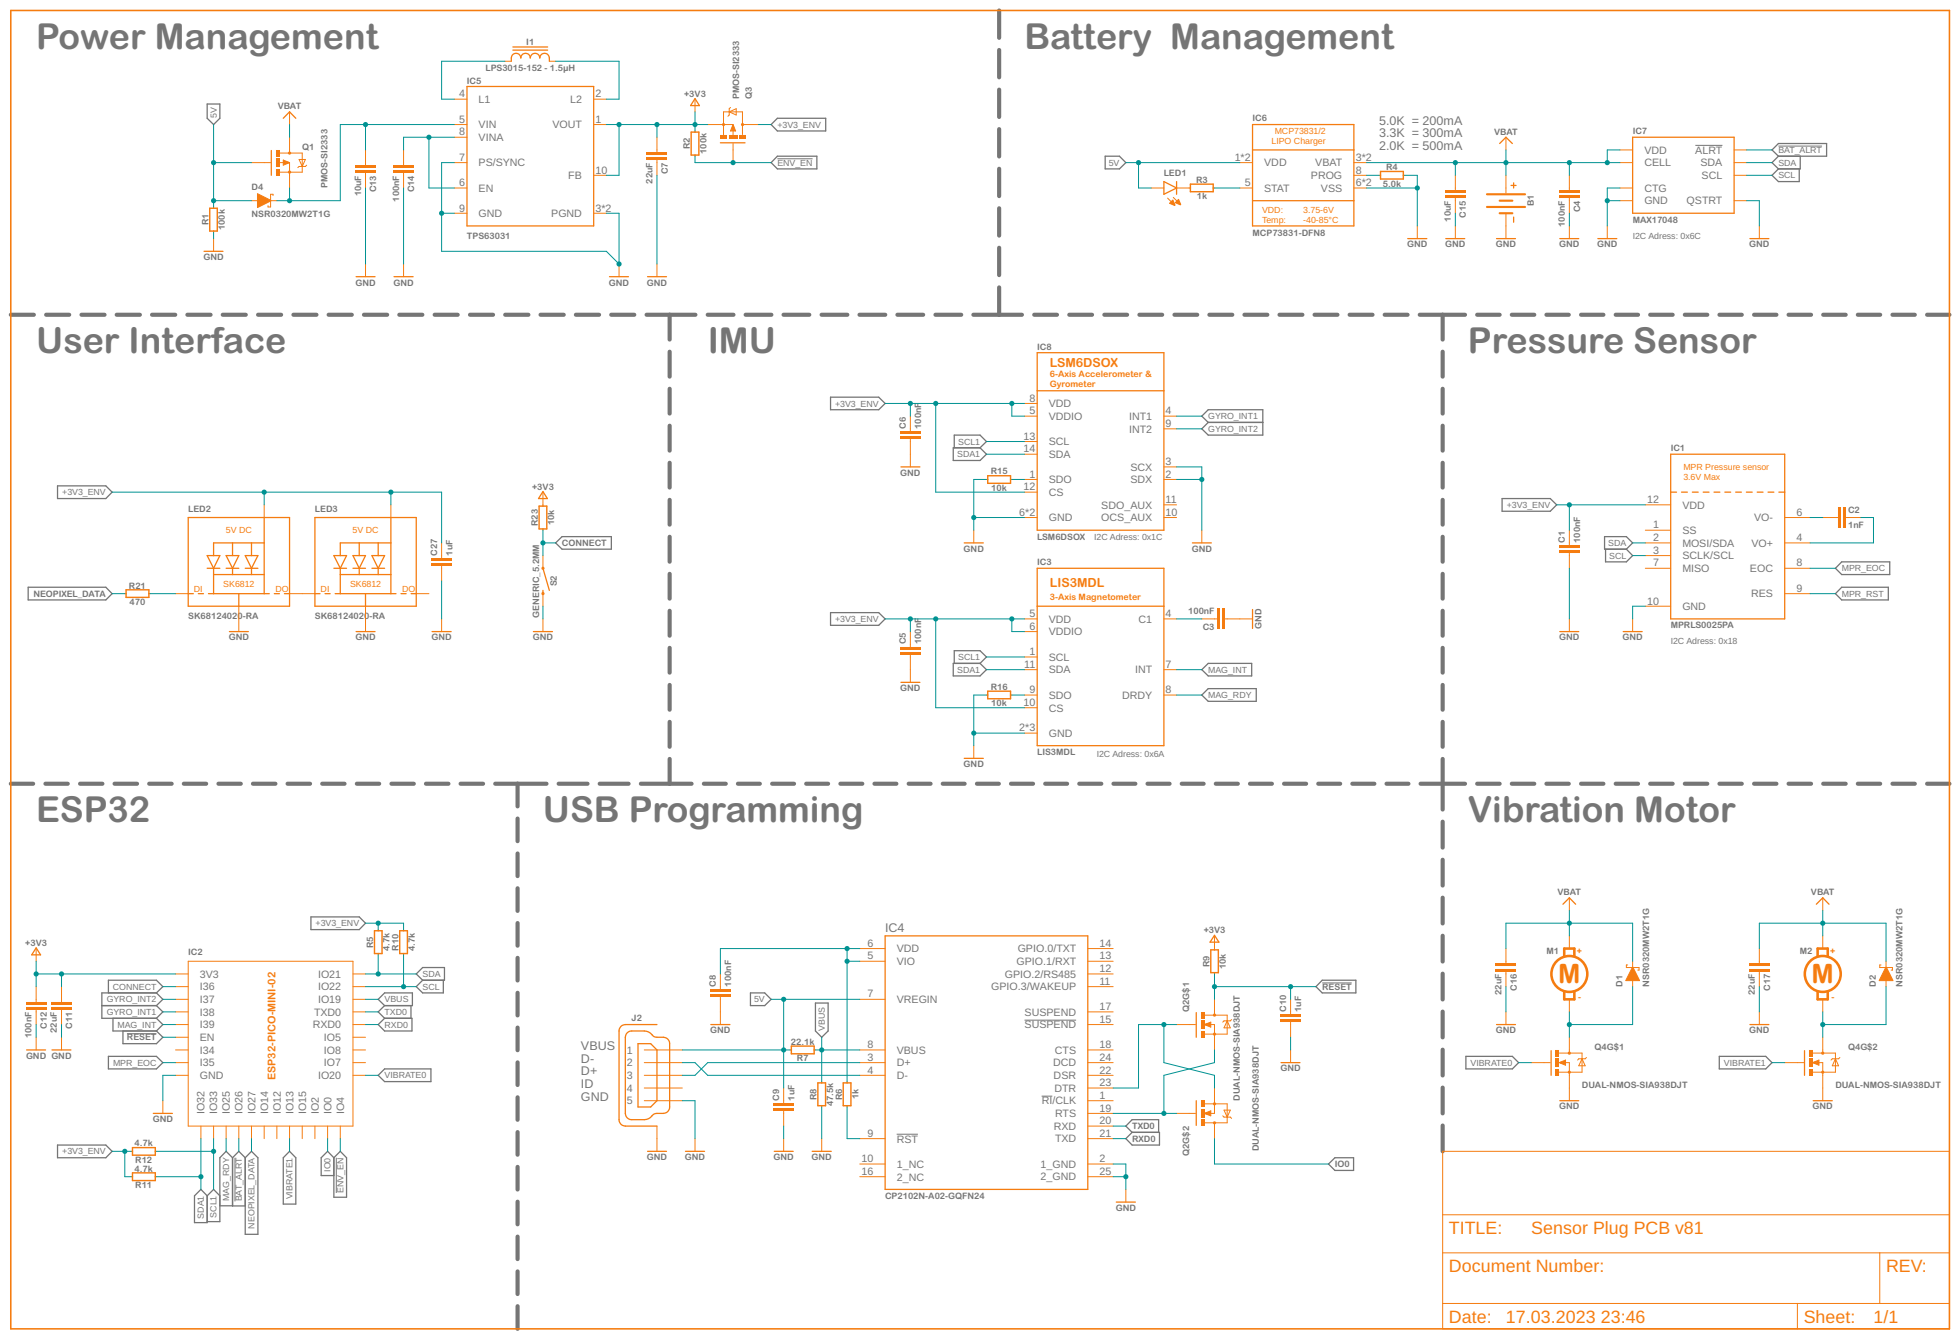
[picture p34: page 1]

10uF GND GND MAX17048 GND GND

MPR Pressure sensor 3.6V Max

CONNECT | | SCL
GYRO_INT2 | VBUS

DUAL-NMOS-SIA938DJT

Date: Sheet: | REV: TITLE: Document Number:

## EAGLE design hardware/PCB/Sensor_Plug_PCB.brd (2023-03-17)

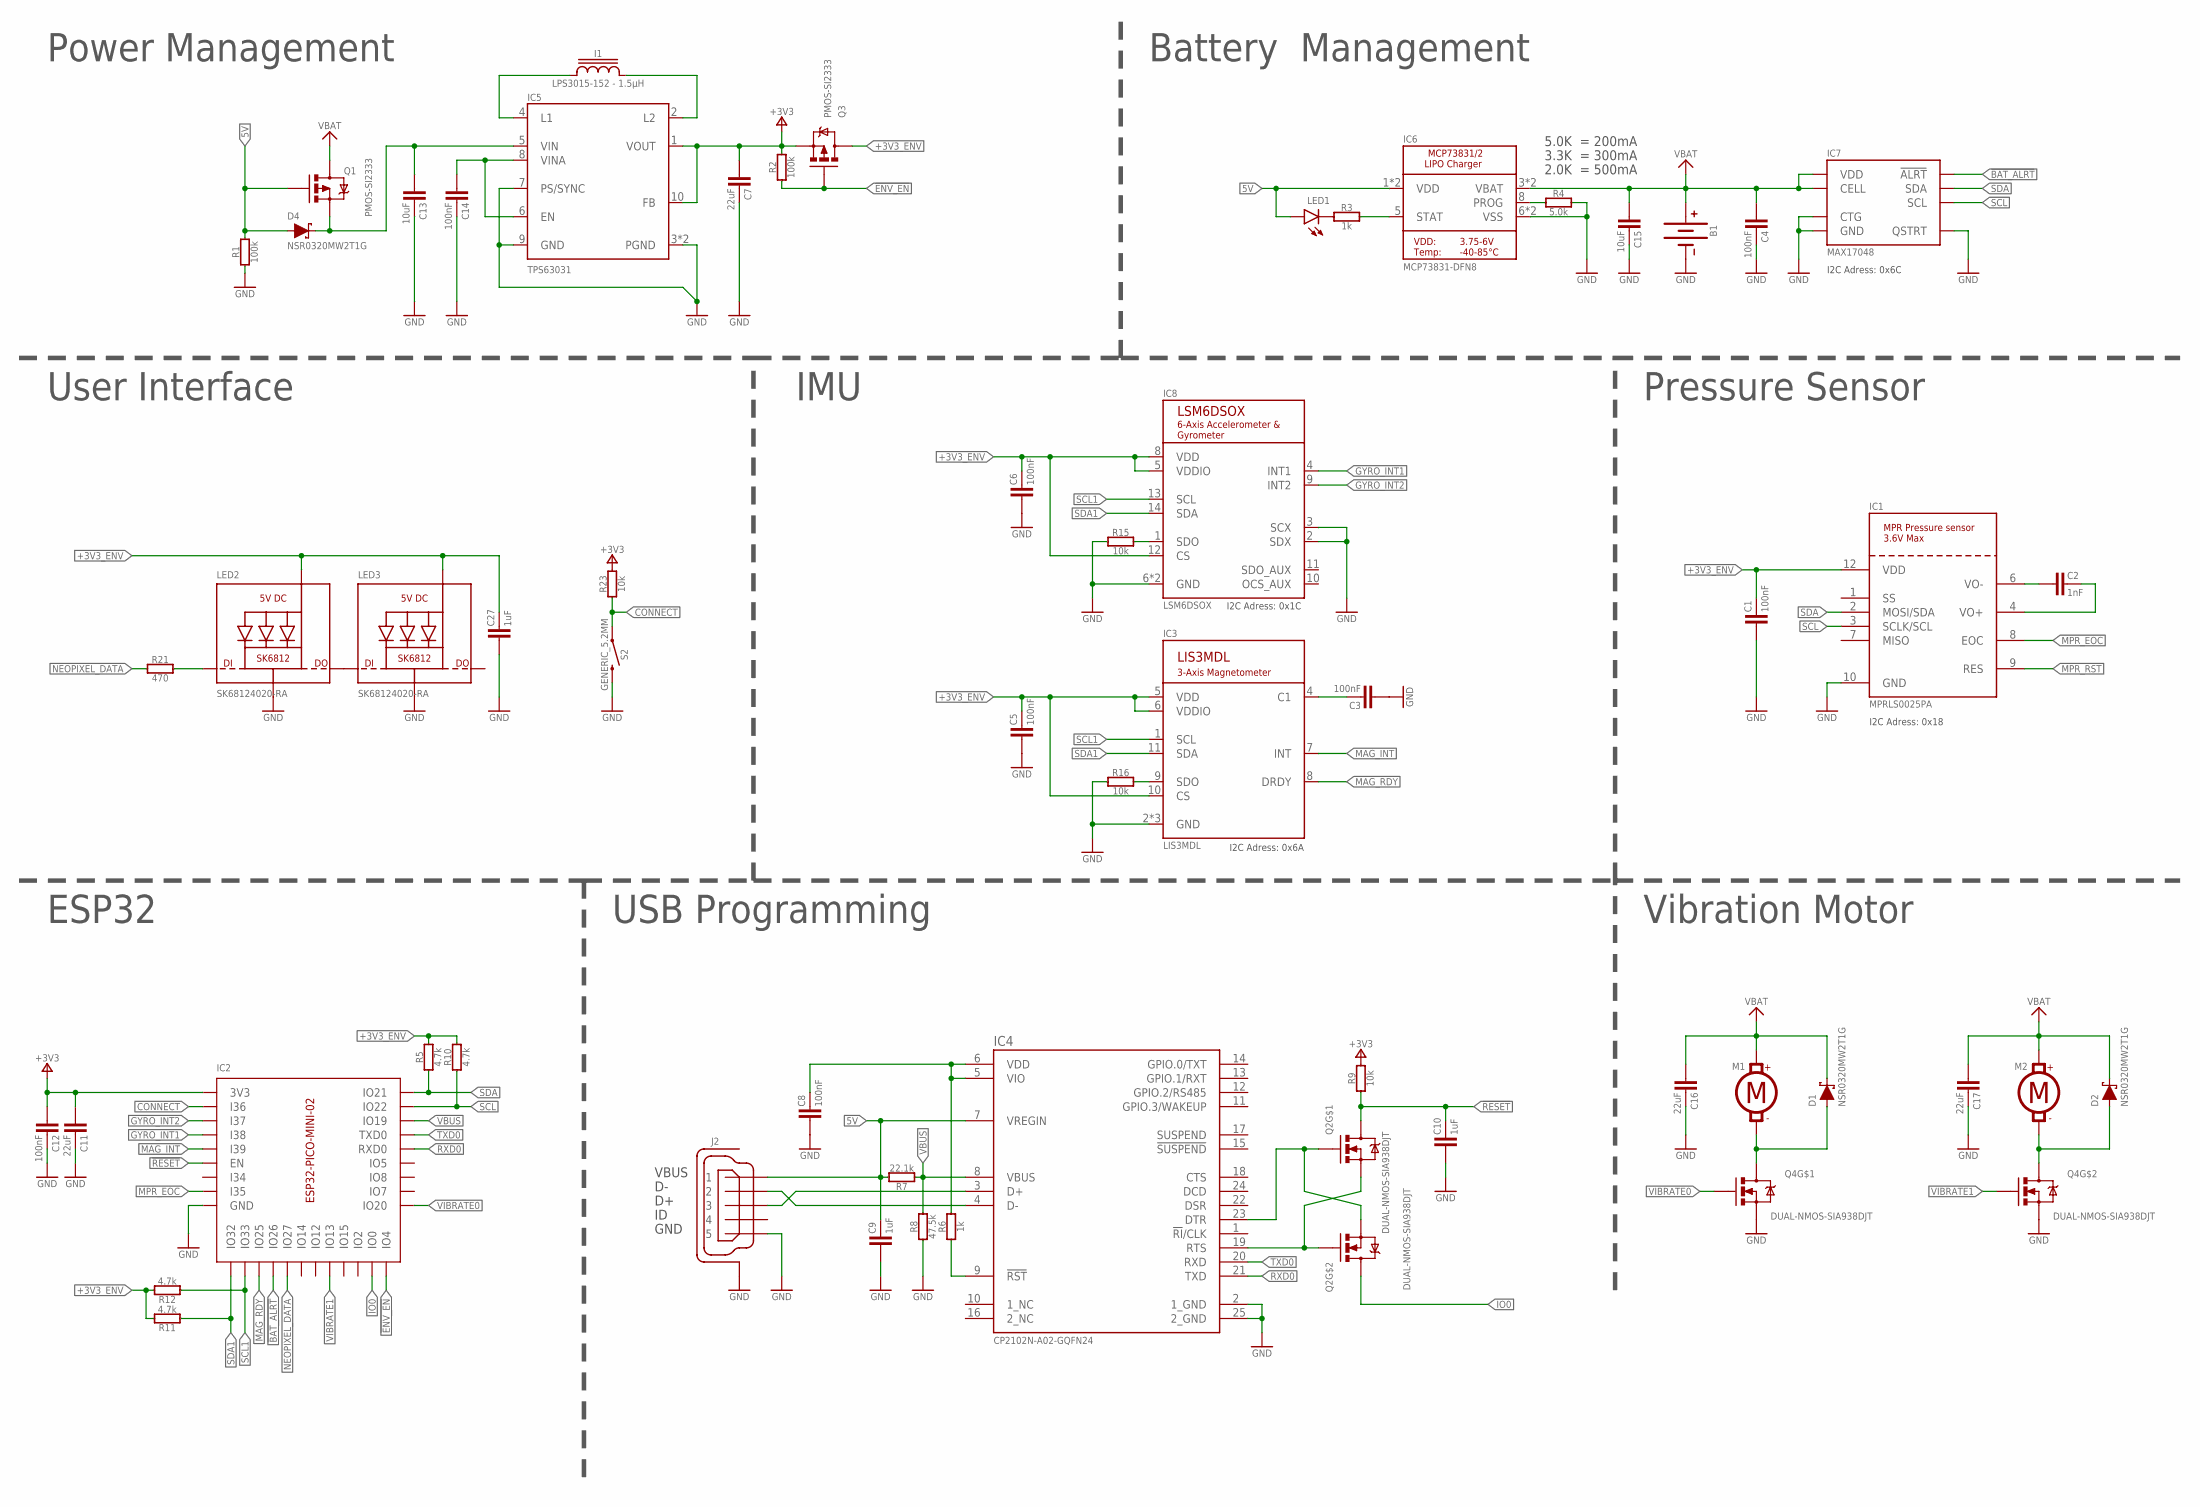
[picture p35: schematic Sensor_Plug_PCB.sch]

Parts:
B1: LIPO-JST_PH_SMDV-02; JST_PH_SMDV-02
C1, C3, C4, C5, C6, C8, C12, C14: 100nF; C0603
C2: 1nF; C0603
C7, C11, C16, C17: 22uF; C0805
C9, C10, C27: 1uF; C0603
C13, C15: 10uF; C0805
D1, D2, D4: NSR0320MW2T1G; SOD-323
I1: LPS3015-152 - 1.5µH; LPS3015
IC1: MPRLS0025PA
IC2: EPS32-PICO-MINI-02; ESP32-PICO-MINI-02
IC3: LIS3MDL; LGA12_2X2MM
IC4: CP2102N-A02-GQFN24; QFN24
IC5: TPS63031; R-PWSON-N10
IC6: MCP73831-DFN8; DFN8_2X3
IC7: MAX17048; DFN8_2X2
IC8: LSM6DSOX; LGA-14L
J2: -; ZX62-AB-5PA
LED1: LED-0603-SIDEVIEW; LED_0603_SIDEVIEW
LED2, LED3: SK68124020-RA; SK6812-4020-SIDE
M1, M2: MOTOR-PADS
Q1, Q3: PMOS-SI2333; SOT23-3
Q2, Q4: DUAL-NMOS-SIA938DJT; POWERPAK_SC70-6L_DUAL
R1, R2: 100k; R0603
R3, R6: 1k; R0603
R4: 5.0k; R0603
R5, R10, R11, R12: 4.7k; R0603
R7: 22.1k; R0603
R8: 47.5k; R0603
R9, R15, R16, R23: 10k; R0603
R21: 470; R0603
S2: GENERIC_5.2MM; C&K_KMS

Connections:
5V: C9.1, D4.A, IC4.7 (VREGIN), IC6.1 (VDD), IC6.2 (VDD), J2.1, LED1.A, Q1.1 (G), R1.2, R7.2
!BAT_ALRT: IC2.P$16 (IO26), IC7.5 (!ALRT)
!ENV_EN: IC2.P$24 (IO4), Q3.1 (G), R2.1
!RESET: C10.1, IC2.P$8 (EN), Q2.6 (D), Q2.7 (D), R9.1
+3V3: C7.2, C11.2, C12.2, IC2.P$3 (3V3), IC5.1 (VOUT), IC5.10 (FB), Q3.2 (S), R2.2, R9.2, R23.2
+3V3_ENV: C1.1, C5.1, C6.1, C27.1, IC1.12 (VDD), IC3.5 (VDD), IC3.6 (VDDIO), IC3.10 (CS), IC8.5 (VDDIO), IC8.8 (VDD), IC8.12 (CS), LED2.VDD, LED3.VDD, Q3.3 (D), R5.2, R10.2, R11.2, R12.2
CHARGING: IC6.5 (STAT), R3.2
CONNECT: IC2.P$4 (I36), R23.1, S2.1, S2.5 (1)
DTR: IC4.23 (DTR), Q2.2 (G), Q2.4 (S)
GND: B1.1 (-), C1.2, C3.2, C4.1, C5.2, C6.2, C7.1, C8.2, C9.2, C10.2, C11.1, C12.1, C13.1, C14.1, C15.1, C16.1, C17.1, C27.2, IC1.10 (GND), IC2.P$1 (GND), IC2.P$2 (GND), IC2.P$11 (GND), IC2.P$14 (GND), IC2.P$36 (GND), IC2.P$37 (GND), IC2.P$38 (GND), IC2.P$39 (GND), IC2.P$40 (GND), IC2.P$41 (GND), IC2.P$42 (GND), IC2.P$43 (GND), IC2.P$44 (GND), IC2.P$45 (GND), IC2.P$46 (GND), IC2.P$47 (GND), IC2.P$48 (GND), IC2.P$49 (GND), IC2.P$50 (GND), IC2.P$51 (GND), IC2.P$52 (GND), IC2.P$53 (GND), IC2.P$54 (GND), IC2.P$55 (GND), IC2.P$56 (GND), IC2.P$57 (GND), IC2.P$58 (GND), IC2.P$59 (GND), IC2.P$60 (GND), IC2.P$61 (GND), IC3.2 (GND), IC3.3 (GND), IC3.12 (GND), IC4.2 (1_GND), IC4.25 (2_GND), IC5.3 (PGND), IC5.7 (PS/SYNC), IC5.9 (GND), IC5.11 (PGND), IC6.6 (VSS), IC6.9 (VSS), IC7.1 (CTG), IC7.4 (GND), IC7.6 (QSTRT), IC7.9 (GND), IC8.2 (SDX), IC8.3 (SCX), IC8.6 (GND), IC8.7 (GND), J2.5, J2.6 (SH), J2.7 (SH), J2.8 (SH), J2.9 (SH), J2.10 (SH), J2.11 (SH), LED2.GND, LED3.GND, Q4.1 (S), Q4.4 (S), R1.1, R4.2, R8.1, R15.1, R16.1, S2.2, S2.3 (2), S2.4 (2)
GYRO_INT1: IC2.P$6 (I38), IC8.4 (INT1)
GYRO_INT2: IC2.P$5 (I37), IC8.9 (INT2)
IO0: IC2.P$23 (IO0), Q2.3 (D), Q2.8 (D)
MAG_INT: IC2.P$7 (I39), IC3.7 (INT)
MAG_RDY: IC2.P$15 (IO25), IC3.8 (DRDY)
MPR_EOC: IC1.8 (EOC), IC2.P$10 (I35)
MPR_RST: IC1.9 (RES)
unnamed: C8.1, IC4.5 (VIO), IC4.6 (VDD), R6.2
unnamed: C2.2, IC1.6 (VO-)
unnamed: C2.1, IC1.4 (VO+)
unnamed: C3.1, IC3.4 (C1)
unnamed: C14.2, IC5.6 (EN), IC5.8 (VINA)
unnamed: I1.1, IC5.4 (L1)
unnamed: I1.2, IC5.2 (L2)
unnamed: IC4.4 (D-), J2.2
unnamed: IC4.3 (D+), J2.3
unnamed: LED1.C, R3.1
unnamed: D1.A, M1.N, Q4.6 (D), Q4.7 (D)
unnamed: IC4.9 (!RST!), R6.1
unnamed: IC6.8 (PROG), R4.1
unnamed: LED2.DOUT (DO), LED3.DIN (DI)
unnamed: D2.A, M2.N, Q4.3 (D), Q4.8 (D)
unnamed: IC8.1 (SDO), R15.2
unnamed: IC3.9 (SDO), R16.2
unnamed: LED2.DIN (DI), R21.1
NEOPIXEL_DATA: IC2.P$17 (IO27), R21.2
RTS: IC4.19 (RTS), Q2.1 (S), Q2.5 (G)
RXD0: IC2.P$30 (RXD0), IC4.21 (TXD)
SCL: IC1.3 (SCLK/SCL), IC2.P$34 (IO22), IC7.7 (SCL), R10.1
SCL1: IC2.P$13 (IO33), IC3.1 (SCL), IC8.13 (SCL), R12.1
SDA: IC1.2 (MOSI/SDA), IC2.P$35 (IO21), IC7.8 (SDA), R5.1
SDA1: IC2.P$12 (IO32), IC3.11 (SDA), IC8.14 (SDA), R11.1
TXD0: IC2.P$31 (TXD0), IC4.20 (RXD)
VBAT: B1.2 (+), C4.2, C15.2, C16.2, C17.2, D1.C, D2.C, IC6.3 (VBAT), IC6.4 (VBAT), IC7.2 (CELL), IC7.3 (VDD), M1.P, M2.P, Q1.3 (D)
VBUS: IC2.P$33 (IO19), IC4.8 (VBUS), R7.1, R8.2
VIBRATE0: IC2.P$26 (IO20), Q4.2 (G)
VIBRATE1: IC2.P$20 (IO13), Q4.5 (G)
VIN: C13.2, D4.C, IC5.5 (VIN), Q1.2 (S)

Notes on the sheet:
Power Management
Battery Management
ESP32
USB Programming
Pressure Sensor
User Interface
IMU
3.3K = 300mA
2.0K = 500mA
I2C Adress: 0x6C
I2C Adress: 0x18
Vibration Motor
I2C Adress: 0x6A
I2C Adress: 0x1C
5.0K = 200mA

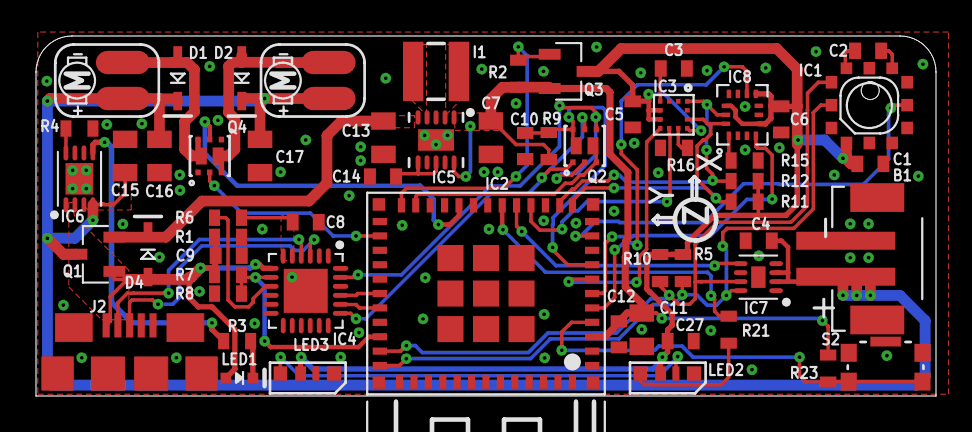
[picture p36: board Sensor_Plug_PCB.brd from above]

Board: 2 copper layers, 50.0 x 20.0 mm, 58 parts (0 on the bottom side), 47 nets.

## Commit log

2023-02-04 Added hardware
    [Sensor_Plug_PCB.brd, Sensor_Plug_PCB.sch, SmartAssPlug_BOM.csv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]
2023-02-04 CSV Syntax
    [SmartAssPlug_BOM.csv]
2023-02-04 More Syntax CSV
    [SmartAssPlug_BOM.csv]
2023-02-05 new PCB export
    [Sensor_Plug_PCB.brd, Sensor_Plug_PCB.sch]
2023-02-06 Updated docs
    [SmartAssPlug_Cap.stl, [T]_SmartAssPlug_Cap.stl]
2023-02-08 finished assembly docs
2023-03-17 Change R5 to reduce charge current
    Charge current was too ambitious leading to excessive heating during charging. This fixes the heat issue.
    [Sensor_Plug_PCB.brd, Sensor_Plug_PCB.sch]
